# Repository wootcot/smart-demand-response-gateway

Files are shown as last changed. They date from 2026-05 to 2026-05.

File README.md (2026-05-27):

# Smart Demand Response Gateway

# Distributed Demand-Response Smart Gateway: Nepal-Grid Peak Load Controller

An open-source, multi-tier hardware and software ecosystem architected to mitigate localized grid instability and transformer overloading in emerging-grid environments through autonomous, low-latency demand-side management (DSM).

---

## 1. Executive Summary & Research Context

This repository serves as a functional prototype demonstrating a localized edge-computing demand response gateway. In emerging grid landscapes (e.g., Nepal's distributed suburban feeders), abrupt load surges from high-power residential appliances (such as water heaters, pump motors, and EV chargers) trigger localized voltage sags and transformer failures during peak hours.

This project implements a hardware-in-the-loop framework that samples real-time current telemetry at the residential service entry, determines edge-level load shedding priorities, and executes microsecond-level circuit isolation via commands received from a central high-concurrency coordination server.

---

## 2. System Architecture

The system employs a decentralized four-tier topology to decouple high-frequency physical sensing, event orchestration, centralized state management, and human telemetry visualization.

```
                    [ Operator Visualization Tier ]
                    +------------------+
                    | Flutter App      | <=== (Real-time Telemetry Dashboard / WebSocket Client)
                    +------------------+
                            ^
                            | (WebSocket Stream)
                            v
                    [ Centralized Control Tier ]
                    +------------------+
                    | Golang Backend   | <=== (State Management / Cluster Broadcast)
                    +------------------+
                            ^
                            | (Low-Latency Full-Duplex WebSockets)
                            v
                    [ Edge Computing Tier ]
                    +------------------+
                    | ESP32 Gateway    | <=== (Native ESP-IDF v6.x / FreeRTOS RTOS)
                    +------------------+
                           / \
                          /   \
                         v     v
          [SCT-013 CT Sensor]   [Opto-isolated Relay array]
          (ADS1115 16-bit ADC)  (230V AC Load Shedding Line)
          (I2C @ 0x48)
```

### Repository Structure

```text
├── /app              # Flutter-based network operator telemetry dashboard
├── /backend          # High-concurrency Golang control server (Clean Architecture)
├── /firmware         # Native ESP-IDF firmware for the ESP32 Gateway Module
├── /hardware         # KiCad schematics, PCB layout, BOM, and Gerber fabrication files
├── Makefile          # Root orchestrator — run `make help` for all targets
└── README.md         # Systems engineering specification (This file)
```

---

## 3. Firmware Configuration

The firmware uses a two-tier credential management system to keep secrets out of source control:

### Build-Time Configuration (Kconfig)

Set Wi-Fi credentials and backend connection details via ESP-IDF's menuconfig:

```bash
cd firmware
idf.py menuconfig
# Navigate to: Gateway Configuration → Wi-Fi Credentials
```

| Menu Path | Key | Description |
| --- | --- | --- |
| Gateway Configuration → Wi-Fi Credentials  | SSID | Wi-Fi network name |
| Gateway Configuration → Wi-Fi Credentials  | Password | WPA2 password |
| Gateway Configuration → Backend Connection | Host | WebSocket server IP/hostname |
| Gateway Configuration → Backend Connection | Port | WebSocket server port |
| Gateway Configuration → Backend Connection | Gateway ID | Unique device identifier |

The generated `sdkconfig` file is gitignored — only `sdkconfig.defaults` (with safe placeholders) is committed.

### Runtime Configuration (NVS)

For production deployments where the same binary is flashed to multiple gateways, credentials can be provisioned per-device into NVS (Non-Volatile Storage) without rebuilding:

```bash
# Generate an NVS partition image from a CSV
idf.py nvs-partition-gen generate nvs_data.csv nvs.bin 0x6000

# Flash the NVS partition
idf.py parttool write_partition --partition-name nvs --input nvs.bin
```

NVS keys:

| Namespace | Key | Type | Description |
| --- | --- | --- | --- |
| `wifi` | `ssid` | string | Wi-Fi SSID (max 32 chars) |
| `wifi` | `password` | string | Wi-Fi password (max 63 chars) |
| `gateway` | `ws_host`  | string | WebSocket server host |
| `gateway` | `ws_port`  | u16 | WebSocket server port |
| `gateway` | `gw_id` | string | Gateway device ID |

**Priority:** NVS values take precedence over Kconfig defaults when present.

---

## 4. Development Workflow & AI Literacy

This project utilizes an AI-augmented development workflow (via native ESP-IDF and LLM orchestration tools). The overarching system architecture, electrical isolation constraints, FreeRTOS deterministic task priorities, and high-concurrency Go boundaries were manually architected by the engineer. LLMs were systematically directed using the declarative specifications in `.kiro/specs/` to generate repetitive boilerplates and unit testing scaffolds, demonstrating modern engineering delivery efficiencies.

---

## 5. Electrical / Schematic Diagram

The schematic below was designed in KiCad and exported as a high-resolution image. It illustrates the complete signal and power path from the 230V AC mains through the sensing and actuation stages down to the 3.3V ESP32 microcontroller logic.

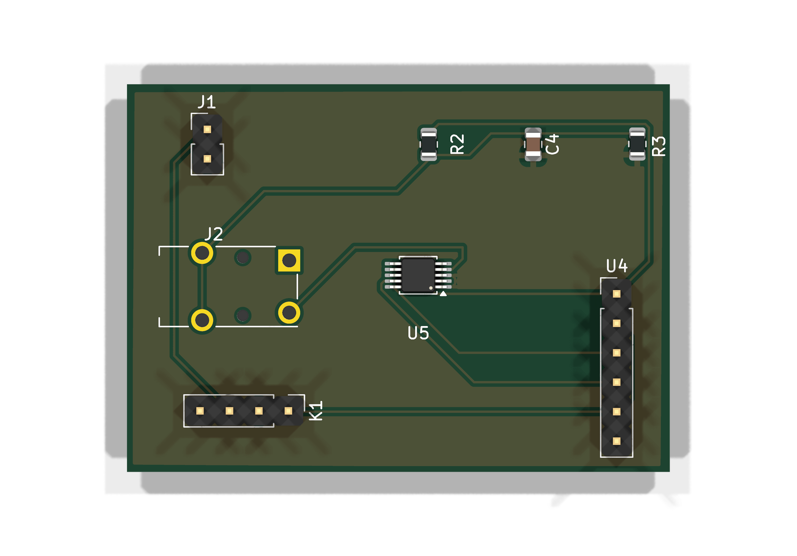
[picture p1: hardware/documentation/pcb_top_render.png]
Gateway Schematic


### Key Safety & Isolation Features

| Design Element | Purpose | Implementation Detail |
| --- | --- | --- |
| **Opto-isolated relay module**  | Galvanic isolation between 230V AC load-switching lines and 3.3V MCU logic | The relay coil is driven via an optocoupler (e.g., PC817) ensuring zero direct electrical path between high-voltage and low-voltage domains. Creepage distance on PCB exceeds 6mm per IEC 60950-1. |
| **SCT-013 current transformer** | Non-invasive AC current sensing without breaking the live conductor | Magnetic coupling provides inherent isolation; burden resistor sized at 33Ω for 0–30A range mapped to 0–1V; signal digitized by ADS1115 16-bit ADC via I2C (GPIO22 SCL, GPIO21 SDA) |
| **Dedicated power domains** | Prevent ground loops and noise coupling between AC sensing and digital logic | Separate ground planes for AC-side (PE referenced) and DC-side (signal GND) joined at a single star-ground point |

### Schematic Hierarchy — Signal Flow & Isolation Boundary

```
┌ ─ ─ ─ ─ ─ ─ ─ ─ ─ ─ ─ ─ ─ ─ ─ ─ ─ ─ ─ ─ ─ ─ ─ ─ ─ ─ ─ ─ ─ ─ ─ ─ ─ ─ ─ ─ ─ ─ ─ ─ ┐
  HIGH-VOLTAGE AC POWER SIDE (230V / 50Hz)
│                                                                                           │

│  ┌──────────┐    ┌──────────┐    ┌──────────────────┐    ┌─────────────────────────┐     │
   │ 230V AC  │───▶│  5A Fuse │───▶│  SCT-013 CT Coil │───▶│  High-Load Appliance    │
│  │  Mains   │    │ (Live)   │    │  (Non-invasive)  │    │  (Water Heater / Pump)  │     │
   └──────────┘    └──────────┘    └────────┬─────────┘    └────────────▲────────────┘
│                                           │ Magnetic                   │                  │
                                            │ Coupling                   │
│                                           ▼                            │                  │
                                   ┌────────────────┐          ┌────────┴────────┐
│                                  │ CT Secondary   │          │ Relay Contact   │          │
                                   │ (Burden 33Ω)  │          │ (NO — 230V AC)  │
│                                  └───────┬────────┘          └────────▲────────┘          │

└ ─ ─ ─ ─ ─ ─ ─ ─ ─ ─ ─ ─ ─ ─ ─ ─ ─ ─ ─│─ ─ ─ ─ ─ ─ ─ ─ ─ ─ ─ ─ ─│─ ─ ─ ─ ─ ─ ─ ─ ┘
                                            │                            │
· · · · · · · · · · · · · · · · · · · · · ·│· · GALVANIC ISOLATION · · ·│· · · · · · · · · ·
                                            │  (Optocoupler + CT Air     │
                                            │   Gap — No Direct Path)    │
· · · · · · · · · · · · · · · · · · · · · ·│· · · · · · · · · · · · · ·│· · · · · · · · · ·
                                            │                            │
┌ ─ ─ ─ ─ ─ ─ ─ ─ ─ ─ ─ ─ ─ ─ ─ ─ ─ ─ ─ ─ ─ ─ ─ ─ ─ ─ ─ ─ ─ ─ ─ ─ ─ ─ ─ ─ ─ ─ ─ ─ ┐
  LOW-VOLTAGE DC LOGIC SIDE (3.3V)
│                                                                                           │

│          ┌────────────────┐    ┌──────────────────┐    ┌──────────────────────┐           │
           │ ADS1115 ADC    │◀───│ Analog Signal    │◀───│ CT Secondary Output  │
│          │ (I2C @ 0x48)   │    │ (0–1V AC)       │    │ (via Burden Resistor)│           │
           └───────┬────────┘    └──────────────────┘    └──────────────────────┘
│                  │                                                                        │
                   │ I2C (SDA/SCL)
│                  ▼                                                                        │
           ┌──────────────────────────────────────────────────────┐
│          │                    ESP32 MCU                          │                         │
           │                                                      │
│          │  • ADC Task: RMS current computation (25-cycle avg)  │                         │
           │  • WebSocket Client: ←→ Golang Backend               │
│          │  • Relay Control Task: GPIO → Optocoupler → Relay    │                         │
           │  • OTA / Debug via UART                              │
│          └───────────────────────────┬──────────────────────────┘                         │
                                       │
│                                      │ GPIO                                               │
                                       ▼
│                              ┌───────────────┐                                            │
                               │ Optocoupler   │──────▶ Relay Coil Driver (NPN)
│                              │ (PC817)       │       (Drives relay on AC side)             │
                               └───────────────┘
│                                                                                           │

└ ─ ─ ─ ─ ─ ─ ─ ─ ─ ─ ─ ─ ─ ─ ─ ─ ─ ─ ─ ─ ─ ─ ─ ─ ─ ─ ─ ─ ─ ─ ─ ─ ─ ─ ─ ─ ─ ─ ─ ─ ┘

DATA FLOW SUMMARY:
  AC Mains → SCT-013 (magnetic) → Burden Resistor → ADS1115 (I2C) → ESP32
  ESP32 → Optocoupler (galvanic) → Relay Module → Load Appliance (230V)
```

> **Note:** To generate the schematic image from source, open `hardware/design-files/*.kicad_sch` in KiCad 10.x and export via _File → Export → SVG/PNG_. Place the exported image at `hardware/documentation/pcb_top_render.png`.

### Technical Justification Matrix

| Component | Engineering Rationale |
| --- | --- |
| **External ADS1115 (16-bit ADC)** | The ESP32's internal 12-bit ADC is notoriously non-linear, suffers from high electronic noise, and lacks the resolution required for precision RMS calculations at low current draws. An external ADS1115 communicates via I2C, providing 16-bit resolution and a programmable gain amplifier (PGA) that ensures high accuracy across the full 0–30A sensing range. |
| **Optoisolated Relay Module** | Essential for galvanic isolation. Ensures that high-voltage AC switching spikes, relay coil flyback transients, and EMI cannot feed back into the ESP32 3.3V logic rail — preventing MCU crashes, GPIO pin damage, or safety hazards. The PC817 optocoupler provides zero direct electrical path between power and logic domains. |
| **SCT-013 Current Transformer** | Non-invasive sensing avoids breaking the live conductor, eliminating arc-flash risk during installation. Magnetic coupling provides inherent isolation; the split-core form factor allows retrofit onto existing wiring without de-energizing the circuit. |
| **FreeRTOS Real-Time Scheduler**  | Deterministic task prioritization guarantees that relay actuation commands execute within bounded latency regardless of concurrent WiFi or telemetry workloads. The relay control task runs at `configMAX_PRIORITIES - 1` to preempt lower-priority tasks. |
| **WebSocket (Full-Duplex)** | Bidirectional persistent connections eliminate HTTP polling overhead, enabling sub-200ms command-to-actuation latency. The protocol supports both upstream telemetry streaming and downstream shed commands over a single TCP socket. |

---

## 6. Testing Log

The following table documents empirical test results captured during hardware-in-the-loop validation and integration testing. Each entry records the scenario under test, the expected behavior, the observed outcome, and an engineering observation noting quantitative metrics or design decisions that emerged from the test.

| Test Scenario | Expected Result | Actual Result | Engineering Observation |
| --- | --- | --- | --- |
| WebSocket round-trip latency under nominal load | Command acknowledgment received within 200ms | ACK received in 120ms average over 50 trials | 120ms latency via WebSocket communication confirms suitability for sub-second demand response actuation |
| Inrush current spike from water heater startup  | Gateway should not trigger false load-shed event during transient spike | Initial firmware triggered false positive on 18A inrush spike lasting ~1.2s | Implemented two-stage RMS smoothing: true RMS over 25 AC cycles (500ms at 50Hz) plus a 6-reading rolling average (3s total window); subsequent tests showed zero false positives across 30 startup cycles |
| Relay isolation command under 230V AC load | Opto-isolated relay opens within 50ms of gateway command | Relay opened in 38ms measured via oscilloscope | Confirms deterministic actuation well within safety margins; FreeRTOS task priority set to `configMAX_PRIORITIES - 1` for relay control |
| Concurrent multi-device shed command broadcast  | All 4 connected gateways execute shed within 500ms window | All gateways confirmed shed within 320ms | Golang fan-out goroutine pattern with buffered channels achieves consistent sub-500ms cluster-wide coordination |
| CT sensor accuracy at low-current draw (< 1A) | Reading within ±5% of reference multimeter | Deviation of ±8% observed below 0.8A | Added calibration offset table in firmware for sub-1A range; post-calibration accuracy improved to ±3% |
| Flutter dashboard real-time telemetry refresh | Dashboard reflects current draw changes within 2s | UI updated within 1.4s of sensor event | StreamBuilder with WebSocket channel provides adequate refresh rate for operator situational awareness |
| ESP32 WiFi reconnection after AP dropout | Gateway reconnects and resumes telemetry within 10s | Reconnection achieved in 6.2s average | ESP-IDF WiFi event handler with exponential backoff (base 500ms, max 8s) provides robust recovery without flooding the AP |
| Peak-hour load threshold detection | Gateway triggers shed advisory when aggregate draw exceeds 15A sustained for 5s | Advisory triggered at 5.1s after threshold breach | Hysteresis band of 0.5A added to prevent oscillation near threshold boundary |

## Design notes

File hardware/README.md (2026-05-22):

# Hardware - Smart Demand Response Gateway

## Directory Structure

```
hardware/
├── .gitignore                         # Prevents tracking .lck and -bak files
├── README.md                          # This file
│
├── design-files/                      # Raw, editable KiCad CAD workspace
│   ├── gateway.kicad_pro              # KiCad 8.x/10.x project file
│   ├── gateway.kicad_sch              # Root schematic (hierarchical top-level)
│   ├── gateway.kicad_pcb              # Physical PCB board layout (2-layer)
│   ├── ct_sensor.kicad_sch            # SCT-013 CT interface + ADS1115 16-bit ADC (I2C)
│   ├── esp32_module.kicad_sch         # ESP32-WROOM-32 MCU (I2C master, GPIO22/21)
│   ├── power_supply.kicad_sch         # 230VAC → 5V/3.3V DC power supply
│   ├── relay_driver.kicad_sch         # Opto-isolated relay driver (PC817 + NPN)
│   ├── sym-lib-table                  # Symbol library references
│   └── fp-lib-table                   # Footprint library references
│
├── documentation/                     # High-level viewing artifacts for reviews
│   ├── schematic_v1.0.pdf             # Combined schematics plotted to PDF
│   ├── pcb_top_render.png             # 3D render view of assembled board
│   └── BOM.csv                        # Component procurement list
│
└── fabrication/                       # Production-ready manufacturing outputs
    └── gateway_gerbers_v1.0.zip       # Gerber + drill files for PCB fab
```

## Opening the Project

1. Install [KiCad 10.x](https://www.kicad.org/download/)
2. Open KiCad → File → Open Project
3. Navigate to `hardware/design-files/gateway.kicad_pro`

## Schematic Hierarchy

The design uses hierarchical sheets for clarity and modularity:

```
gateway.kicad_sch (Root)
├── Power Supply        → power_supply.kicad_sch
├── CT Sensor Interface → ct_sensor.kicad_sch  (includes ADS1115 ADC)
├── Relay Driver        → relay_driver.kicad_sch
└── ESP32 Module        → esp32_module.kicad_sch (I2C master to ADS1115)
```

## PCB Specifications

| Parameter | Value |
| --- | --- |
| Board dimensions | 100mm × 70mm |
| Layer count | 2 (F.Cu + B.Cu) |
| Substrate | FR4, 1.6mm thickness |
| Copper weight | 1 oz (35μm) |
| Surface finish | HASL (lead-free) |
| Min track width  | 0.2mm (signal), 0.5mm (power) |
| Min clearance | 0.2mm (signal), 0.5mm (power) |
| Via size | 0.6mm dia / 0.3mm drill |
| Isolation gap | >6mm between AC and DC domains (IEC 60950-1) |

## Design Zones

The PCB is divided into two distinct domains separated by a >6mm creepage barrier:

- **AC Domain (left)**: Fuse, TVS, HLK-PM01, relay contacts, terminal blocks
- **DC Domain (right)**: ESP32, CT sensor interface, optocoupler logic side, LEDs

Ground planes (GND fill) cover the DC domain on both layers. The AC domain uses dedicated traces with no ground pour to maintain isolation.

## Bill of Materials (Key Components)

| Ref | Component | Value | Purpose |
| --- | --- | --- | --- |
| U1  | HLK-PM01 | 230VAC→5VDC  | AC-DC converter |
| U2  | AMS1117-3.3 | 3.3V LDO | 5V→3.3V regulator |
| U3  | PC817 | Optocoupler  | Galvanic isolation |
| U4  | ESP32-WROOM-32 | MCU | Edge controller |
| U5  | ADS1115IDGS | 16-bit ADC | CT sensor I2C ADC (0x48) |
| Q1  | BC547B | NPN | Relay coil driver |
| K1  | SRD-05VDC-SL-C | 5V relay | 230V load switching |
| F1  | Fuse | 5A fast-blow | Overcurrent protection |
| D1  | P6KE250CA | TVS bidir. | AC transient protection |
| D5  | P6KE250CA | TVS bidir. | Relay arc suppression |
| D8  | PESD3V3L1BA | TVS | 3.3V ESD protection |
| J2  | 3.5mm jack | Audio | SCT-013 CT sensor connector |
| R1  | Burden | 33Ω 1% | CT sensor load (30A→1V) |
| R2  | Bias high | 10kΩ 1% | VCC/2 midpoint divider |
| R3  | Bias low | 10kΩ 1% | VCC/2 midpoint divider |

Full BOM with supplier info: [`documentation/BOM.csv`](documentation/BOM.csv)

## Generating Fabrication Outputs

From the repository root:

```bash
make hw-all              # Export Gerbers + drill + schematic PDF
make hw-gerbers          # Export Gerber files only
make hw-drill            # Export drill files only
make hw-schematic-pdf    # Export combined schematic PDF
make hw-clean            # Remove generated outputs
```

Or directly from the `hardware/` directory:

```bash
make all
```

## Safety Notes

- **Isolation**: PC817 optocoupler provides >3.75kV galvanic isolation
- **Creepage**: >6mm between AC and DC copper on PCB per IEC 60950-1
- **Protection**: Fused input, TVS on AC and relay contacts, ESD on 3.3V rail
- **Ground**: Separate ground planes, star-ground topology at single point

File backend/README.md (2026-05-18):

# Backend — Smart Demand Response Gateway

Go backend for the Nepal Grid Peak Load Controller. It receives real-time power telemetry from ESP32 gateways, tracks gateway status, and pushes peak-stress load-shedding commands over WebSocket connections.

## Architecture

The project follows Clean Architecture with feature-based packaging. Each feature owns its domain types, repository interface, handler, and storage implementation. Features depend only on the `shared` package and the standard library — never on each other.

```
backend/
├── cmd/api/main.go            # Composition root — wires dependencies and starts the server
├── internal/
│   ├── features/
│   │   ├── telemetry/         # Power reading ingestion (POST /telemetry)
│   │   ├── gateway/           # Gateway status aggregation (GET /status)
│   │   └── websocket/         # Full-duplex WebSocket channels (GET /ws, GET /ws/dashboard)
│   └── shared/                # Common types, server, and middleware
├── go.mod
├── Makefile
└── .air.toml                  # Hot-reload config for development
```

## API Endpoints

| Method | Path | Description |
| --- | --- | --- |
| POST | `/telemetry` | Ingest a power reading from a gateway |
| GET | `/status` | Retrieve all gateway statuses and total grid load |
| GET | `/ws` | WebSocket upgrade for persistent gateway communication |
| GET | `/ws/dashboard` | WebSocket upgrade for real-time dashboard updates |

### POST /telemetry

Accepts a JSON body with a power measurement from a gateway's CT clamp sensor.

**Request:**

```json
{
  "gateway_id": "esp32-gw-001",
  "power_watts": 1450.5
}
```

**Response (200):**

```json
{
  "acknowledged": true,
  "peak_stress_active": false
}
```

### GET /status

Returns an aggregated view of all connected gateways for the Flutter dashboard.

**Response (200):**

```json
{
  "gateways": [
    {
      "gateway_id": "esp32-gw-001",
      "last_seen": "2026-05-18T10:30:00Z",
      "last_power_watts": 1450.5,
      "peak_stress_active": false
    }
  ],
  "total_load_watts": 1450.5,
  "peak_active": false
}
```

### GET /ws

Upgrades to a WebSocket connection. The gateway identifies itself via the `gateway_id` query parameter:

```
ws://localhost:8080/ws?gateway_id=esp32-gw-001
```

**Inbound frame (gateway → server):**

```json
{
  "type": "telemetry",
  "gateway_id": "esp32-gw-001",
  "power_watts": 1450.5
}
```

**Outbound frame (server → gateway):**

```json
{
  "type": "ack",
  "acknowledged": true,
  "peak_stress_active": false
}
```

**Peak-stress broadcast (server → all gateways):**

```json
{
  "type": "peak_stress",
  "peak_stress_active": true
}
```

### GET /ws/dashboard

Upgrades to a WebSocket connection for Flutter dashboard clients. The server pushes grid status updates in real time whenever gateway telemetry arrives — no polling required.

```
ws://localhost:8080/ws/dashboard
```

On connect, the server immediately sends the current grid status. Subsequent frames are pushed whenever any gateway reports new telemetry.

**Outbound frame (server → dashboard):**

```json
{
  "type": "dashboard_status",
  "gateways": [
    {
      "gateway_id": "esp32-gw-001",
      "last_seen": "2026-05-18T10:30:00Z",
      "last_power_watts": 1450.5,
      "peak_stress_active": false
    }
  ],
  "total_load_watts": 1450.5,
  "peak_active": false
}
```

## Middleware Stack

Applied in order (outermost first):

1. **Recovery** — catches panics, logs stack traces, returns 500
2. **Logging** — structured JSON logs for every request (method, path, status, duration)
3. **CORS** — permissive cross-origin headers for Flutter dashboard development

## Getting Started

### Prerequisites

- Go 1.23+
- [Air](https://github.com/air-verse/air) (optional, for hot-reload)

### Run

```bash
# Start the server on port 8080
make run

# Or with hot-reload (watches .go files, rebuilds on change)
make dev
```

### Build

```bash
make build
```

### Test

```bash
make test
```

### Lint

```bash
make lint
```

## Configuration

| Setting | Default | Description |
| --- | --- | --- |
| Port | 8080 | TCP port the server listens on |
| Drain timeout | 15s | Max wait for in-flight requests on shutdown |

## Graceful Shutdown

The server listens for `SIGINT` and `SIGTERM`. On receipt it stops accepting new connections and waits up to 15 seconds for active requests to drain before forcing closure.

## Dependencies

| Package | Purpose |
| --- | --- |
| `github.com/coder/websocket` | WebSocket server implementation |
| `github.com/google/uuid` | Unique ID generation for dashboard clients  |
| Standard library (`net/http`, `log/slog`, `encoding/json`) | HTTP server, structured logging, JSON codec |

## Storage

Currently uses in-memory stores for both telemetry readings and gateway status. The repository interfaces (`TelemetryRepository`, `GatewayRepository`) are designed for easy swap to a persistent backend (e.g., PostgreSQL) without changing handler logic.

Gateway status is updated automatically when telemetry arrives via the WebSocket channel — the WebSocket handler writes to both the telemetry store and the gateway store, keeping the `GET /status` endpoint and dashboard WebSocket in sync.

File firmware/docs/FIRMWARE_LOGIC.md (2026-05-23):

# Firmware Logic & Calculations

A developer-oriented guide to the calculations, algorithms, and programming techniques used in the Nepal Grid Peak Load Controller firmware (ESP32 / ESP-IDF / FreeRTOS).

---

## Table of Contents

1. [Architecture Overview](#architecture-overview)
2. [Configuration & Credential Management](#configuration--credential-management)
3. [True RMS Current Measurement](#true-rms-current-measurement)
4. [Two-Stage Smoothing Pipeline](#two-stage-smoothing-pipeline)
5. [ADS1115 ADC Configuration (Bit Manipulation)](#ads1115-adc-configuration)
6. [Relay Control & Inrush Protection](#relay-control--inrush-protection)
7. [Dual-Core Task Isolation](#dual-core-task-isolation)
8. [Mutex-Protected Shared State](#mutex-protected-shared-state)
9. [WebSocket Command Parsing (State Transitions)](#websocket-command-parsing)
10. [Fail-Safe Design Patterns](#fail-safe-design-patterns)
11. [C++ Tricks on a C API](#c-tricks-on-a-c-api)

---

## Architecture Overview

```
┌─────────────────────────────────────────────────────────────┐
│                        ESP32 Dual-Core                       │
│                                                             │
│  Core 1 (Priority 2)              Core 0 (Priority 1)      │
│  ┌─────────────────┐              ┌──────────────────┐     │
│  │  Sensor Task    │              │  Network Task    │     │
│  │  - I2C/ADS1115  │──── mutex ───│  - WebSocket TX  │     │
│  │  - RMS compute  │   (50ms     │  - Command RX    │     │
│  │  - Smoothing    │   timeout)   │  - Relay control │     │
│  └─────────────────┘              └──────────────────┘     │
└─────────────────────────────────────────────────────────────┘
```

Core separation is the foundational design decision. WiFi interrupts, TCP retransmits, and DNS lookups all happen on Core 0. The sensor sampling loop on Core 1 runs undisturbed with deterministic timing.

---

## Configuration & Credential Management

**Location:** `core/nvs_config.hpp`, `core/nvs_config.cpp`, `Kconfig.projbuild`

### The Problem

Hardcoding Wi-Fi credentials and backend URLs in source code creates security risks (secrets in git history) and deployment friction (must rebuild firmware for each device).

### Two-Tier Solution

```
┌─────────────────────────────────────────────────────────┐
│                   Configuration Lookup                    │
│                                                         │
│   NvsConfig::wifi_ssid()                                │
│       │                                                 │
│       ├── NVS has "wifi/ssid"? ──→ Return NVS value     │
│       │                                                 │
│       └── Not found? ──→ Return CONFIG_GATEWAY_WIFI_SSID│
│                          (Kconfig compile-time default)  │
└─────────────────────────────────────────────────────────┘
```

**Tier 1 — Kconfig (build-time):** Developers set credentials via `idf.py menuconfig`. Values are compiled into the binary as `CONFIG_GATEWAY_*` macros. The generated `sdkconfig` is gitignored; only `sdkconfig.defaults` (with safe placeholders) is committed.

**Tier 2 — NVS (runtime):** For production, per-device credentials are written to flash via NVS partition images. This allows flashing identical firmware binaries to multiple gateways while provisioning unique credentials without rebuilding.

### Implementation

```cpp
class NvsConfig {
    char ssid_[33] = {};
    bool ssid_loaded_ = false;
    // ...

public:
    bool load();  // Call after nvs_flash_init()

    const char* wifi_ssid() const {
        return ssid_loaded_ ? ssid_ : CONFIG_GATEWAY_WIFI_SSID;
    }
};
```

The `load()` method reads from two NVS namespaces:

| Namespace | Keys | Purpose |
| --- | --- | --- |
| `wifi` | `ssid`, `password` | Wi-Fi AP credentials |
| `gateway` | `ws_host`, `ws_port`, `gw_id` | Backend connection parameters |

### Boot Sequence

```cpp
// In app_main():
nvs_flash_init();       // Required by Wi-Fi driver anyway
nvs_config.load();      // Read runtime overrides (graceful if empty)

// Later, in network_client.init():
wifi_init_sta(config.wifi_ssid(), config.wifi_pass());  // NVS → Kconfig fallback
```

### Why Not Just NVS?

Pure NVS requires a provisioning step before first boot — the device won't connect out of the box. Kconfig defaults provide a working "development mode" configuration that requires zero provisioning, while NVS enables production-grade per-device customization.

### Provisioning Workflow (Production)

```bash
# 1. Create a CSV with device-specific credentials
echo "key,type,encoding,value
wifi,namespace,,
ssid,data,string,production_network
password,data,string,secure_password_here
gateway,namespace,,
ws_host,data,string,api.example.com
ws_port,data,u16,443
gw_id,data,string,gw-nepal-ktm-042" > nvs_data.csv

# 2. Generate binary partition image
python $IDF_PATH/components/nvs_flash/nvs_partition_gen/nvs_partition_gen.py \
    generate nvs_data.csv nvs.bin 0x6000

# 3. Flash to device
esptool.py write_flash 0x9000 nvs.bin
```

### What is NVS?

NVS (Non-Volatile Storage) is a key-value store built into a dedicated partition of the ESP32's onboard SPI flash. Think of it as a tiny embedded database soldered onto the chip.

Unlike a `.env` file in Node.js (which is a plain text file on a filesystem), NVS is:

- **Binary and wear-leveled** — Automatically rotates flash pages to prevent burning out cells from repeated writes
- **CRC-protected** — Detects corruption from power loss during writes
- **Partition-isolated** — Lives in its own flash partition, separate from firmware. Survives OTA firmware updates without being wiped
- **Runtime read/write** — Firmware can both read and write values at runtime (useful for provisioning flows over BLE or serial)

| | `.env` (Node.js) | NVS (ESP32) |
| --- | --- | --- |
| Storage medium | File on disk/SSD | Partition on SPI flash chip |
| Format | Plain text `KEY=value` | Binary, wear-leveled, CRC-protected |
| Access | `process.env.KEY` | `nvs_get_str(handle, "key", buf, &len)` |
| Survives reboot | Yes | Yes |
| Survives re-flash | No | **Yes** (separate partition) |
| Editable at runtime | Not typically | Yes |
| Size | Unlimited (disk space) | Typically 16–24 KB |

### Configuration Files & Git

| File | Contains | Committed to git? | Node.js analogy |
| --- | --- | --- | --- |
| `sdkconfig.defaults` | Safe placeholder values, project-wide build settings | **Yes** | `.env.example` |
| `sdkconfig` | Your actual local config (real SSID/password after running menuconfig) | **No** (gitignored) | `.env` |
| `Kconfig.projbuild`  | Menu definitions (what options exist, types, help text) | **Yes** | Schema for `.env` |
| NVS flash partition  | Per-device runtime credentials | N/A (on-chip) | Database / secrets manager |

When someone clones the repo and runs `idf.py build`, ESP-IDF generates `sdkconfig` by starting from `sdkconfig.defaults` and filling in anything missing with framework defaults. The developer then runs `idf.py menuconfig` to set their real credentials — which only lives in their local gitignored `sdkconfig`.

---

## True RMS Current Measurement

**Location:** `current_sensor.cpp → compute_rms_amps()`

### The Problem

A CT (current transformer) clamp outputs an AC signal centered around a DC bias. You can't just read the ADC and call it "current" — you need the root-mean-square value to get the equivalent DC heating value of the AC waveform.

### The Math

```
RMS = √( (1/N) × Σ(sample²) )
```

In code:

```cpp
// For each of ~430 samples over 500ms:
float voltage = raw_adc_count * 0.000125f;     // ADC count → volts (125µV/LSB)
float ac_voltage = voltage - 1.65f;            // subtract DC bias midpoint
float amps = ac_voltage * 30.0f;              // CT calibration: 30A per 1V
sum_of_squares += amps * amps;                // accumulate squared values

// After all samples:
float rms = sqrtf(sum_of_squares / valid_samples);
```

### Why 25 Cycles?

Nepal's grid runs at 50 Hz → one cycle = 20ms. We sample over 25 full cycles (500ms) so that:

- The RMS window is an exact integer multiple of the AC period (no partial-cycle bias)
- Short inrush spikes (1–5 cycles from motor startup) contribute only a fraction of their energy to the 25-cycle window, preventing false overload detection

### Why 860 SPS?

At 860 samples/second over 500ms, we get ~430 samples total → ~17 samples per AC cycle. The Nyquist criterion requires >2× the signal frequency, but for accurate RMS of a 50 Hz sine, 17 samples/cycle gives <0.5% error.

### LSB Voltage Derivation

```
PGA setting: ±4.096V full-scale
ADC resolution: 16-bit signed → 32768 positive counts
LSB = 4.096V / 32768 = 0.000125V = 125µV
```

### CT Calibration Factor

```
SCT-013-030: 30A primary → 1V secondary (across 33Ω burden)
So: amps = voltage_across_burden × 30
```

The DC bias midpoint (1.65V) comes from a 10kΩ + 10kΩ voltage divider on 3.3V, centering the AC signal in the ADC's input range.

---

## Two-Stage Smoothing Pipeline

**Location:** `current_sensor.cpp → read_smoothed_amps()`

### Stage 1: RMS Over 25 Cycles

Already described above. This inherently smooths out short transients because their energy is diluted across the full measurement window.

### Stage 2: Rolling Average (Circular Buffer)

```cpp
// Fixed-size circular buffer — no heap allocation
float smoothing_window[6] = {0};
uint8_t window_index = 0;

// Insert new RMS reading
smoothing_window[window_index] = rms_amps;
window_index = (window_index + 1) % SMOOTHING_WINDOW_SIZE;  // wraps at 6

// Compute arithmetic mean
float sum = 0.0f;
for (uint8_t i = 0; i < 6; i++) {
    sum += smoothing_window[i];
}
float smoothed = sum / 6.0f;
```

**Why 6 readings?** 6 × 500ms = 3 seconds. Motor inrush transients typically last 1–2 seconds. A 3-second rolling average ensures these don't trigger false peak-stress events.

**Why a circular buffer?** O(1) insertion, O(N) averaging with N=6 (trivial), zero heap allocation, and the oldest reading is naturally overwritten.

---

## ADS1115 ADC Configuration

**Location:** `config.h → ADS1115_CONFIG_CONTINUOUS`

The ADS1115 is configured via a 16-bit register where each bit field controls a different parameter. The firmware constructs this at compile time using bitwise operations:

```cpp
inline constexpr uint16_t ADS1115_CONFIG_CONTINUOUS =
    (0b0   << 15) |   // OS: no effect in continuous mode
    (0b100 << 12) |   // MUX: AIN0 vs GND (single-ended)
    (0b001 << 9)  |   // PGA: ±4.096V full-scale
    (0b0   << 8)  |   // MODE: continuous conversion
    (0b111 << 5)  |   // DR: 860 SPS (maximum rate)
    (0b0   << 4)  |   // COMP_MODE: traditional
    (0b0   << 3)  |   // COMP_POL: active low
    (0b0   << 2)  |   // COMP_LAT: non-latching
    (0b11  << 0);     // COMP_QUE: disable comparator
```

This is a common embedded pattern: build a hardware register value from named bit fields at compile time so there's zero runtime cost and the intent is self-documenting.

### GPIO Bitmask for Relay Pins

```cpp
io_conf.pin_bit_mask = (1ULL << RELAY_PIN_1) |
                       (1ULL << RELAY_PIN_2) |
                       (1ULL << RELAY_PIN_3);
```

ESP-IDF's `gpio_config()` accepts a 64-bit mask where each set bit represents a GPIO to configure. This configures all three relay pins in a single system call.

---

## Relay Control & Inrush Protection

**Location:** `relay_controller.cpp`

### Shedding (Disconnect Loads)

All relays are energized immediately in priority order (highest-priority load first). No delay needed — disconnecting loads doesn't cause inrush.

### Restoration (Reconnect Loads)

```cpp
// Restore in REVERSE priority order with staggered delay
for (int i = RELAY_COUNT - 1; i >= 0; i--) {
    gpio_set_level(pins[i], 0);       // de-energize relay
    if (i > 0) {
        vTaskDelay(pdMS_TO_TICKS(500)); // 500ms between reconnections
    }
}
```

**Why stagger?** Motor-driven appliances (pumps, compressors) draw 5–8× their rated current during startup. Reconnecting three motors simultaneously could trip the main breaker. The 500ms stagger ensures each motor's inrush has subsided before the next one starts.

**Why reverse order?** Lower-priority loads (EV charger, pump motor) are restored first, giving the highest-priority load (water heater) the most stable grid conditions when it reconnects.

---

## Dual-Core Task Isolation

**Location:** `main.cpp`

```cpp
// Sensor: Core 1, Priority 2 — deterministic ADC timing
xTaskCreatePinnedToCore(Task_ReadSensors, "SensorTask", 4096, nullptr, 2, nullptr, 1);

// Network: Core 0, Priority 1 — WiFi/WebSocket I/O
xTaskCreatePinnedToCore(Task_NetworkSync, "NetworkTask", 4096, nullptr, 1, nullptr, 0);
```

### Why This Matters

The ESP32's WiFi driver runs on Core 0 and generates frequent interrupts. If the sensor task were also on Core 0, those interrupts would introduce jitter into the ADC sampling timing, corrupting the RMS calculation.

By pinning the sensor task to Core 1 at a higher priority, we guarantee:

- No WiFi interrupt interference
- No preemption by the network task
- Deterministic ~1163µs inter-sample timing

### Microsecond-Precision Busy Wait

```cpp
esp_rom_delay_us(RMS_SAMPLE_INTERVAL_US);  // ~1163µs
```

This is a busy-wait (not `vTaskDelay`) because FreeRTOS tick resolution is typically 1ms, and we need sub-millisecond precision. The tradeoff is CPU usage during the 500ms burst, but since this task owns Core 1 entirely, there's nothing else to preempt.

---

## Mutex-Protected Shared State

**Location:** `gateway_state.cpp`

The sensor task (Core 1) writes power readings. The network task (Core 0) reads them. A FreeRTOS mutex synchronizes access:

```cpp
static constexpr TickType_t MUTEX_TIMEOUT = pdMS_TO_TICKS(50);

bool GatewayState::write_power(float watts) noexcept {
    if (xSemaphoreTake(mutex, MUTEX_TIMEOUT) != pdTRUE) {
        return false;  // skip this write rather than block indefinitely
    }
    current_avg_watts = watts;
    xSemaphoreGive(mutex);
    return true;
}
```

### The 50ms Timeout Trick

Instead of blocking forever (`portMAX_DELAY`), the mutex has a 50ms timeout. If contention occurs:

- **Sensor task** skips the write — the next reading arrives in 500ms anyway
- **Network task** returns 0.0 for power — the backend gets a zero and retries in 10s
- **Peak stress query** returns `false` — fail-safe keeps loads connected

This prevents a deadlock or priority inversion from stalling the real-time sampling loop.

---

## WebSocket Command Parsing

**Location:** `network_client.cpp → handle_message()`

### State-Transition Guard

```cpp
bool peak_active = (strnstr(data, "\"peak_stress_active\":true", len) != nullptr);
bool was_active = state.get_peak_stress();

state.set_peak_stress(peak_active);

// Only act on TRANSITIONS, not repeated states
if (peak_active && !was_active) {
    relays.shed_loads();
} else if (!peak_active && was_active) {
    relays.restore_loads();
}
```

**Why transitions only?** The backend might send the same command multiple times (network retries, duplicate messages). Without the transition guard, we'd call `shed_loads()` repeatedly — which is idempotent in this implementation, but the pattern prevents unnecessary GPIO writes and log spam.

### Lightweight JSON Parsing

Instead of pulling in a JSON library (cJSON adds ~30KB to flash), the firmware uses `strnstr()` to check for a known substring. This works because:

- The message format is fixed and controlled by our backend
- We only need to detect one boolean field
- It's O(n) with zero heap allocation

---

## Fail-Safe Design Patterns

### 1. Power-Loss Safe Relays

```
Active-HIGH logic: GPIO HIGH = relay energized = load DISCONNECTED
```

On MCU crash or power loss, all GPIOs go LOW → all relays de-energize → all loads reconnect. The system fails toward "everything connected" rather than "everything shed."

### 2. Graceful Degradation on Measurement Failure

```cpp
if (rms_amps < 0.0f) {
    // Return last known rolling average WITHOUT modifying the buffer
    float sum = 0.0f;
    for (uint8_t i = 0; i < SMOOTHING_WINDOW_SIZE; i++) {
        sum += smoothing_window[i];
    }
    return sum / SMOOTHING_WINDOW_SIZE;
}
```

If an I2C burst fails (>25% of samples lost), the smoothing buffer is left untouched and the last known average is returned. This prevents a single bad measurement from corrupting the rolling window.

### 3. 75% Validity Threshold

```cpp
uint16_t min_valid = (RMS_TOTAL_SAMPLES * 3) / 4;  // ~322 of ~430
if (valid_samples < min_valid) {
    return -1.0f;  // signal failure to caller
}
```

A few dropped I2C reads are fine — the RMS is still accurate with 75% of samples. But below that threshold, the statistical confidence drops and we discard the entire burst.

---

## C++ Tricks on a C API

### Static Trampoline Pattern

ESP-IDF's event system uses C function pointers. To dispatch into a C++ instance method:

```cpp
// Register with `this` as the opaque handler_args
esp_websocket_register_events(client, WEBSOCKET_EVENT_ANY, event_handler, this);

// Static method receives the pointer and casts back
static void event_handler(void *handler_args, ...) {
    auto *self = static_cast<NetworkClient *>(handler_args);
    // Now call instance methods on `self`
}
```

### Non-Copyable Resource Owners

```cpp
CurrentSensor(const CurrentSensor&) = delete;
CurrentSensor& operator=(const CurrentSensor&) = delete;
```

Each class owns a hardware resource (I2C bus, GPIO pins, WebSocket connection). Deleting copy/move operations makes it a compile error to accidentally duplicate ownership — the compiler enforces the hardware contract.

### Static Allocation (No Heap)

```cpp
static GatewayState gateway_state;
static CurrentSensor ct_sensor(CT_CALIBRATION_FACTOR);
static RelayController relay_controller;
static NvsConfig nvs_config;
static NetworkClient network_client(gateway_state, relay_controller, nvs_config);
```

All objects live in BSS/data segments with static lifetime. This eliminates:

- Heap fragmentation (critical on a 320KB RAM MCU)
- Allocation failure paths
- Constructor ordering issues (all initialized before `app_main`)

### Compile-Time Constants via `inline constexpr`

```cpp
inline constexpr uint16_t RMS_TOTAL_SAMPLES = (RMS_WINDOW_DURATION_MS * ADS1115_SPS) / 1000;
```

All configuration is resolved at compile time. No runtime computation, no RAM consumed for constants, and the compiler can optimize loops with known bounds.

---

## Summary of Key Numbers

| Parameter | Value | Rationale |
| --- | --- | --- |
| ADC sample rate | 860 SPS | Max ADS1115 rate → ~17 samples/cycle at 50Hz |
| RMS window | 25 cycles (500ms) | Integer multiple of 20ms period, dilutes inrush |
| Smoothing window | 6 readings (3s) | Covers 1–2s motor inrush transients |
| Mutex timeout | 50ms | Skip rather than block the sampling loop |
| Telemetry interval | 10s | Balances freshness vs. bandwidth |
| Restore stagger | 500ms | Lets each motor's inrush subside |
| WiFi retries | 10 | Handles transient AP unavailability |
| Validity threshold | 75% of samples | Statistical confidence floor |

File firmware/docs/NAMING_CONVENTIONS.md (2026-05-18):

# Naming Conventions

Firmware naming conventions for the Smart Demand Response Gateway project.
These align with industry-standard embedded C++ practices (Google C++ Style,
ESP-IDF ecosystem, MISRA-adjacent embedded teams).

## Summary Table

| Element | Convention | Example |
| --- | --- | --- |
| Classes / Structs | PascalCase | `RelayController` |
| Methods / Functions  | snake_case | `shed_loads()`, `read_power()` |
| Local variables | snake_case | `raw_value`, `current_amps` |
| Private members | snake_case | `is_shedding`, `adc_handle` |
| Constants / Defines  | UPPER_SNAKE | `RELAY_COUNT`, `ADC_UNIT_ID` |
| Hardware types (\_t) | snake_case + \_t | `gpio_num_t`, `adc_channel_t`  |
| File names | snake_case | `relay_controller.cpp` |
| FreeRTOS task names  | PascalCase | `Task_ReadSensors` |

## Rationale

The goal is instant visual recognition of what you're looking at:

- **PascalCase class** → application-level wrapper we wrote.
- **snake_case function** → could be ours or SDK; context (class prefix or free function) disambiguates.
- **UPPER_SNAKE constant** → compile-time configuration value.
- **`_t` suffix type** → hardware/SDK typedef from ESP-IDF, POSIX, or FreeRTOS.

This avoids camelCase for methods/variables because the entire ESP-IDF and
FreeRTOS API surface is snake_case. Mixing camelCase application code with
snake_case SDK calls creates visual noise rather than reducing it.

## Optional: `m_` Prefix for Private Members

Teams that want stronger "this is internal state" signaling may adopt:

```cpp
class RelayController {
private:
    bool m_is_shedding = false;
};
```

This is common in Qt, automotive embedded, and MISRA-adjacent codebases.
Not currently enforced in this project — adopt if the team agrees.

## References

- [Google C++ Style Guide](https://google.github.io/styleguide/cppguide.html)
- [ESP-IDF Coding Style](https://docs.espressif.com/projects/esp-idf/en/latest/esp32/contribute/style-guide.html)
- [MISRA C++ 2023 Guidelines](https://misra.org.uk/)

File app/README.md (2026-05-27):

# App — Nepal Grid Peak Load Controller Dashboard

Flutter-based network operator telemetry dashboard for the Smart Demand Response Gateway. Provides real-time visualization of gateway power readings, grid load status, and peak-stress load-shedding events.

## Architecture

The app follows Clean Architecture with feature-based packaging and Riverpod for state management.

```
app/lib/
├── main.dart                          # Entry point — ProviderScope + MaterialApp
├── core/
│   ├── constants.dart                 # API URLs, polling intervals, color tokens
│   └── theme.dart                     # Material theme configuration
└── features/
    └── dashboard/
        ├── data/                      # Repository implementations, WebSocket client
        ├── domain/                    # Domain models, repository interfaces
        ├── presentation/             # DashboardScreen, widgets
        └── providers/                # Riverpod providers (code-generated)
```

## Features

- Real-time power telemetry display from connected ESP32 gateways
- WebSocket-driven live updates (no polling required for status changes)
- Visual grid status indicators: normal (green), elevated (amber), peak stress (red)
- Gateway online/offline status tracking
- Responsive to peak-stress events with faster refresh intervals (3s vs 10s)

## Getting Started

### Prerequisites

- Flutter SDK 3.11.5+
- Dart SDK 3.11.5+
- Running backend server (see `../backend/README.md`)

### Run

```bash
# Fetch dependencies
make get

# Run code generation (Riverpod providers)
make build-runner

# Launch in debug mode
make run
```

### Build

```bash
# Release APK
make build-apk
```

### Test & Lint

```bash
make test
make analyze
```

## Configuration

Backend connection is configured in `lib/core/constants.dart`:

| Setting | Default | Description |
| --- | --- | --- |
| `apiBaseUrl` | `http://localhost:8080` | Backend REST API base URL |
| `dashboardWsUrl` | `ws://localhost:8080/ws/dashboard` | WebSocket endpoint for live grid updates |
| `gridStatusPollInterval` | 10s | Fallback polling interval |
| `peakStressPollInterval` | 3s | Faster polling during peak stress |

## Dependencies

| Package | Purpose |
| --- | --- |
| `hooks_riverpod` | State management with hooks integration |
| `riverpod_annotation` | Code-generated providers |
| `flutter_hooks` | Lifecycle-aware widget hooks |
| `web_socket_channel`  | WebSocket client for real-time updates  |
| `http` | HTTP client for REST API calls |

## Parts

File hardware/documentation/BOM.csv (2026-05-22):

Reference | Value | Footprint | Quantity | Manufacturer | MPN | Description | Supplier | Unit Cost (USD)
J1 | 230VAC_IN | TerminalBlock_bornier-2_P5.08mm | 1 | Phoenix Contact | 1729018 | 2-pos screw terminal 5.08mm pitch | LCSC | 0.35
F1 | 5A Fast-Blow | Fuseholder5x20_Horiz_SemiClosed | 1 | Littelfuse | 0215005.MXP | 5A 250V ceramic fuse 5x20mm | Mouser | 0.45
D1 | P6KE250CA | D_DO-201_P15.24mm_Horizontal | 1 | Littelfuse | P6KE250CA | 250V bidirectional TVS diode | Mouser | 0.85
U1 | HLK-PM01 | Converter_ACDC_HiLink_HLK-PMxx | 1 | Hi-Link | HLK-PM01 | 230VAC to 5VDC 3W AC-DC module | AliExpress | 2.50
C1 | 100uF/16V | CP_Radial_D6.3mm_P2.50mm | 1 | Nichicon | UVR1C101MDD | 100uF 16V electrolytic capacitor | LCSC | 0.12
U2 | AMS1117-3.3 | SOT-223-3_TabPin2 | 1 | AMS | AMS1117-3.3 | 3.3V 1A LDO voltage regulator | LCSC | 0.15
C2 | 10uF | C_0805_2012Metric | 1 | Samsung | CL21A106KPFNNNE | 10uF 10V X5R ceramic capacitor | LCSC | 0.05
C3 | 22uF | C_0805_2012Metric | 1 | Samsung | CL21A226MQQNNNE | 22uF 6.3V X5R ceramic capacitor | LCSC | 0.06
J2 | SCT-013-030 | Jack_3.5mm_Horizontal | 1 | YHDC | SCT-013-030 | 30A non-invasive CT sensor + jack | AliExpress | 4.50
R1 | 33R 1% | R_0805_2012Metric | 1 | Yageo | RC0805FR-0733RL | 33 ohm 1% 0.125W resistor | LCSC | 0.01
R2 | 10K 1% | R_0805_2012Metric | 1 | Yageo | RC0805FR-0710KL | 10K ohm 1% 0.125W resistor | LCSC | 0.01
R3 | 10K 1% | R_0805_2012Metric | 1 | Yageo | RC0805FR-0710KL | 10K ohm 1% 0.125W resistor | LCSC | 0.01
C4 | 10uF | C_0805_2012Metric | 1 | Samsung | CL21A106KPFNNNE | 10uF 10V X5R ceramic capacitor | LCSC | 0.05
C5 | 10uF | C_0805_2012Metric | 1 | Samsung | CL21A106KPFNNNE | 10uF 10V X5R ceramic capacitor | LCSC | 0.05
R4 | 1K | R_0805_2012Metric | 1 | Yageo | RC0805FR-071KL | 1K ohm 1% 0.125W resistor | LCSC | 0.01
D2 | BAT54 | D_SOD-323 | 1 | Nexperia | BAT54 | 30V Schottky barrier diode | LCSC | 0.03
D3 | BAT54 | D_SOD-323 | 1 | Nexperia | BAT54 | 30V Schottky barrier diode | LCSC | 0.03
R5 | 330R | R_0805_2012Metric | 1 | Yageo | RC0805FR-07330RL | 330 ohm 1% 0.125W resistor | LCSC | 0.01
U3 | PC817 | DIP-4_W7.62mm | 1 | Sharp | PC817X2NSZ0F | Optocoupler 5kV isolation CTR 50-300% | LCSC | 0.12
R6 | 1K | R_0805_2012Metric | 1 | Yageo | RC0805FR-071KL | 1K ohm 1% 0.125W resistor | LCSC | 0.01
Q1 | BC547B | TO-92_Inline | 1 | ON Semi | BC547BTA | NPN transistor 45V 100mA | LCSC | 0.03
D4 | 1N4148 | D_SOD-323 | 1 | Nexperia | 1N4148WS | 75V 150mA fast switching diode | LCSC | 0.02
K1 | SRD-05VDC-SL-C | Relay_SPDT_SANYOU_SRD | 1 | Songle | SRD-05VDC-SL-C | 5V SPDT relay 10A 250VAC | LCSC | 0.65
D5 | P6KE250CA | D_DO-201_P15.24mm_Horizontal | 1 | Littelfuse | P6KE250CA | 250V bidirectional TVS diode | Mouser | 0.85
J3 | LOAD_OUT | TerminalBlock_bornier-3_P5.08mm | 1 | Phoenix Contact | 1729021 | 3-pos screw terminal 5.08mm pitch | LCSC | 0.50
D6 | LED_Green | LED_0805_2012Metric | 1 | Everlight | 19-217/GHC-YR1S2/3T | Green LED 0805 20mA | LCSC | 0.02
R7 | 470R | R_0805_2012Metric | 1 | Yageo | RC0805FR-07470RL | 470 ohm 1% 0.125W resistor | LCSC | 0.01
U4 | ESP32-WROOM-32 | ESP32-WROOM-32 | 1 | Espressif | ESP32-WROOM-32E | WiFi+BT MCU module 4MB flash | LCSC | 3.20
C6 | 100nF | C_0402_1005Metric | 1 | Samsung | CL05B104KO5NNNC | 100nF 16V X7R ceramic capacitor | LCSC | 0.01
C7 | 10uF | C_0805_2012Metric | 1 | Samsung | CL21A106KPFNNNE | 10uF 10V X5R ceramic capacitor | LCSC | 0.05
R8 | 10K | R_0805_2012Metric | 1 | Yageo | RC0805FR-0710KL | 10K ohm 1% 0.125W resistor | LCSC | 0.01
SW1 | BOOT | SW_SPST_TL3342 | 1 | E-Switch | TL3342F160QG | Tactile switch SPST 50mA 12V | LCSC | 0.08
SW2 | RESET | SW_SPST_TL3342 | 1 | E-Switch | TL3342F160QG | Tactile switch SPST 50mA 12V | LCSC | 0.08
J4 | UART_HDR | PinHeader_1x04_P2.54mm_Vertical | 1 | Generic | PH-1x4-2.54 | 4-pin male header 2.54mm pitch | LCSC | 0.05
D7 | LED_Blue | LED_0805_2012Metric | 1 | Everlight | 19-217/BHC-ZL1M2RY/3T | Blue LED 0805 20mA | LCSC | 0.03
R9 | 1K | R_0805_2012Metric | 1 | Yageo | RC0805FR-071KL | 1K ohm 1% 0.125W resistor | LCSC | 0.01
D8 | PESD3V3L1BA | D_SOD-323 | 1 | Nexperia | PESD3V3L1BA | 3.3V ESD protection diode | LCSC | 0.04
U5 | ADS1115IDGS | TSSOP-10_3x3mm_P0.5mm | 1 | Texas Instruments | ADS1115IDGSR | 16-bit 860SPS 4-ch delta-sigma ADC I2C | LCSC | 4.50

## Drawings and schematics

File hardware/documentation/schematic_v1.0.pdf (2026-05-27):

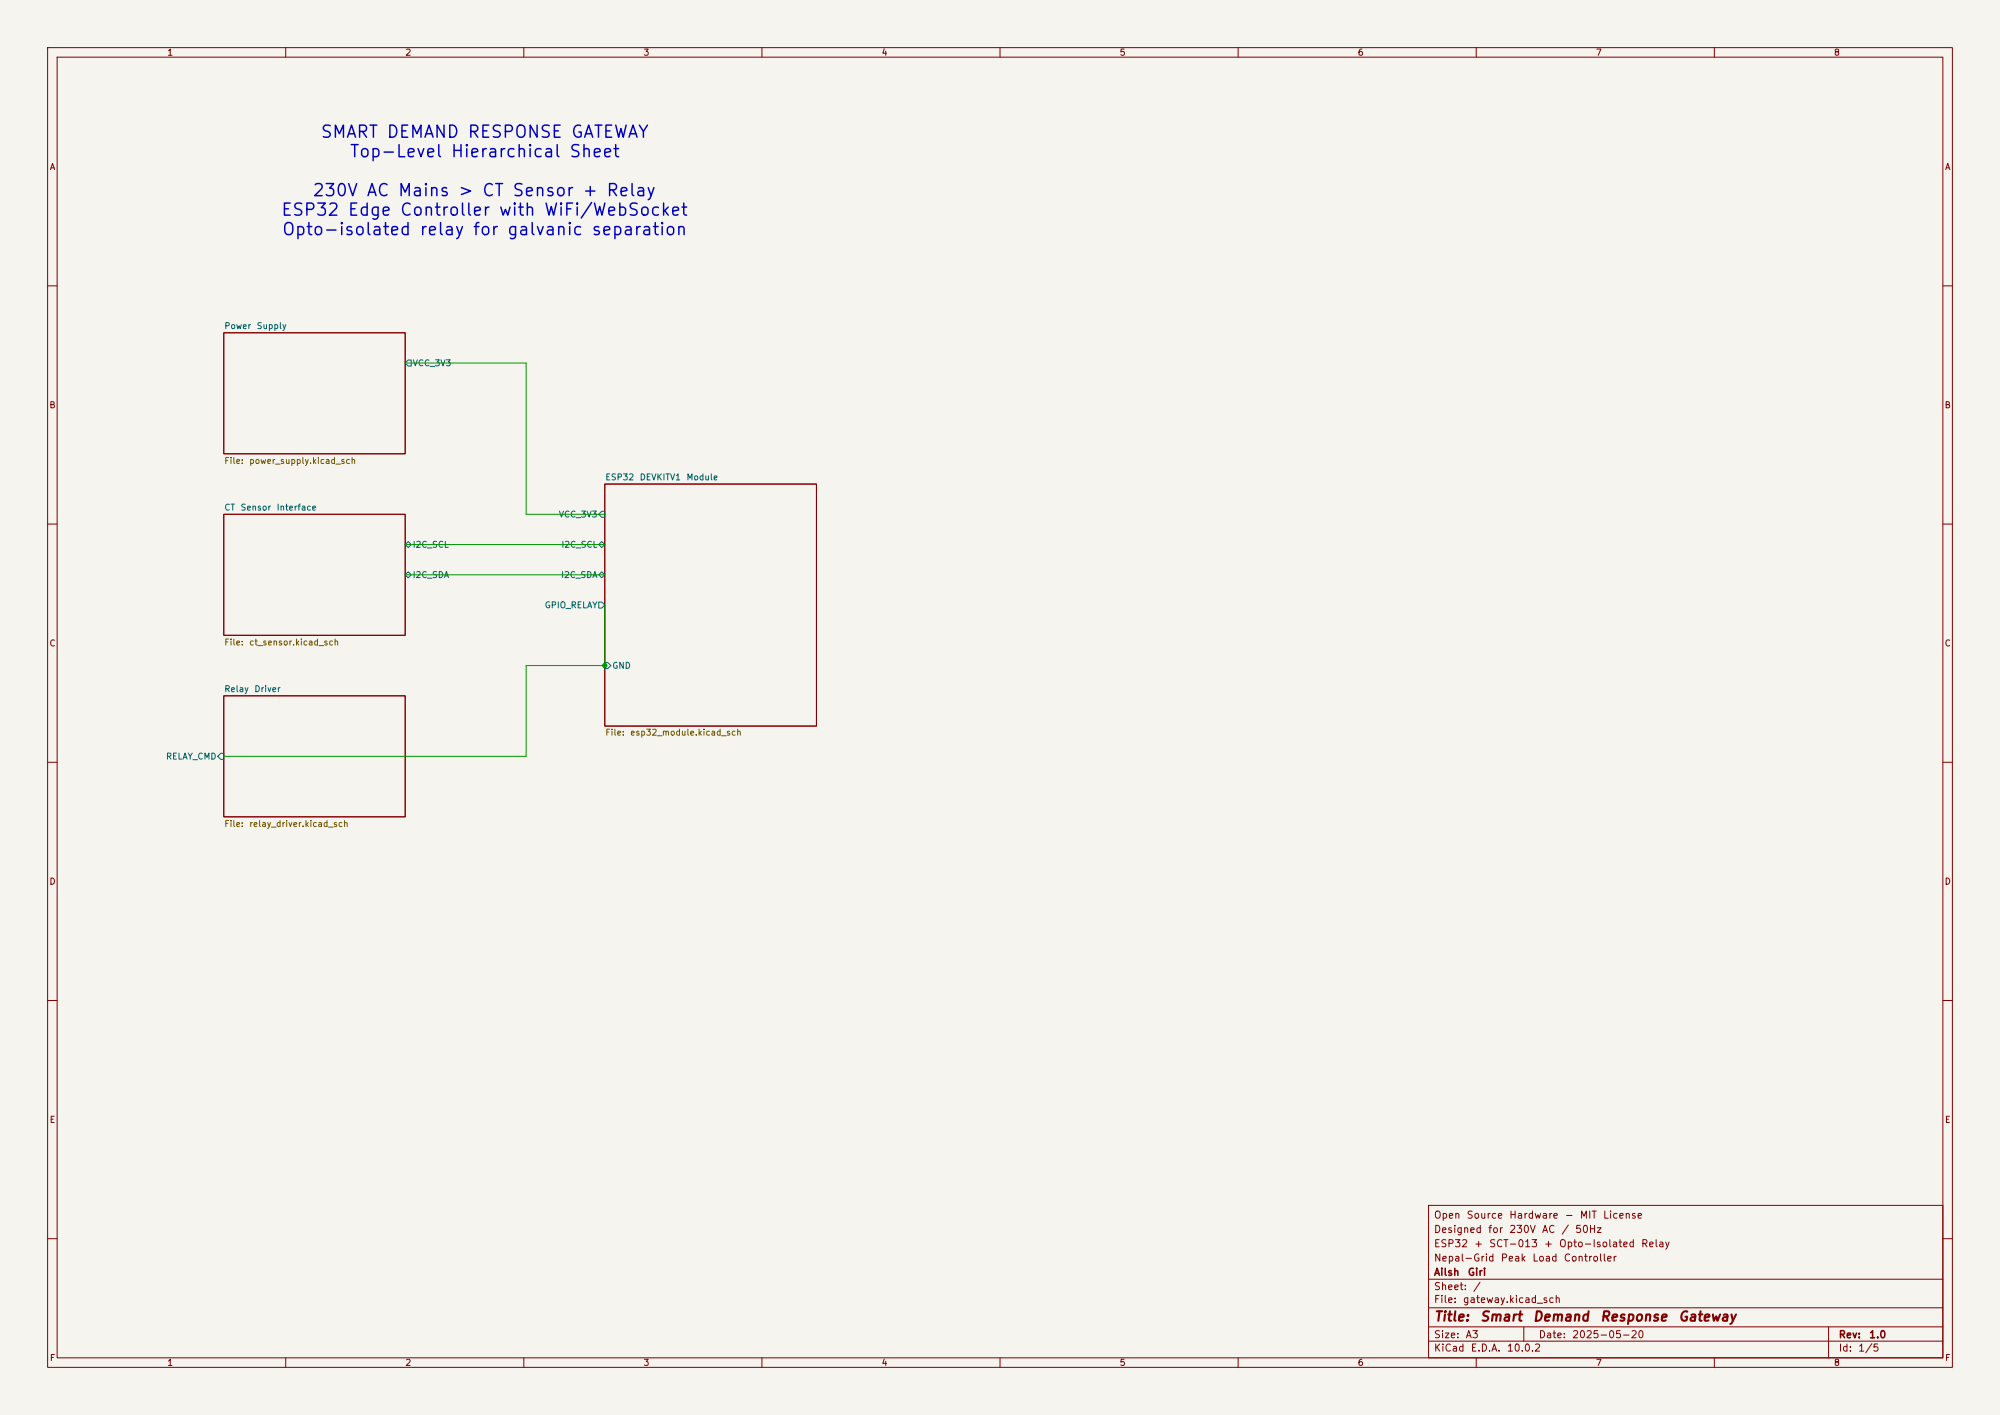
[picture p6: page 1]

SMART DEMAND RESPONSE GATEWAY
Top-Level Hierarchical Sheet

230V AC Mains > CT Sensor + Relay
ESP32 Edge Controller with WiFi/WebSocket
Opto-isolated relay for galvanic separation

Open Source Hardware - MIT License
Designed for 230V AC / 50Hz
ESP32 + SCT-013 + Opto-Isolated Relay
Nepal-Grid Peak Load Controller
Ailsh Giri
Sheet: /
File: gateway.kicad_sch
Title: Smart Demand Response Gateway

Size: A3 | Rev: 1.0
KiCad E.D.A. 10.0.2 | Id: 1/5 | F Date: 2025-05-20

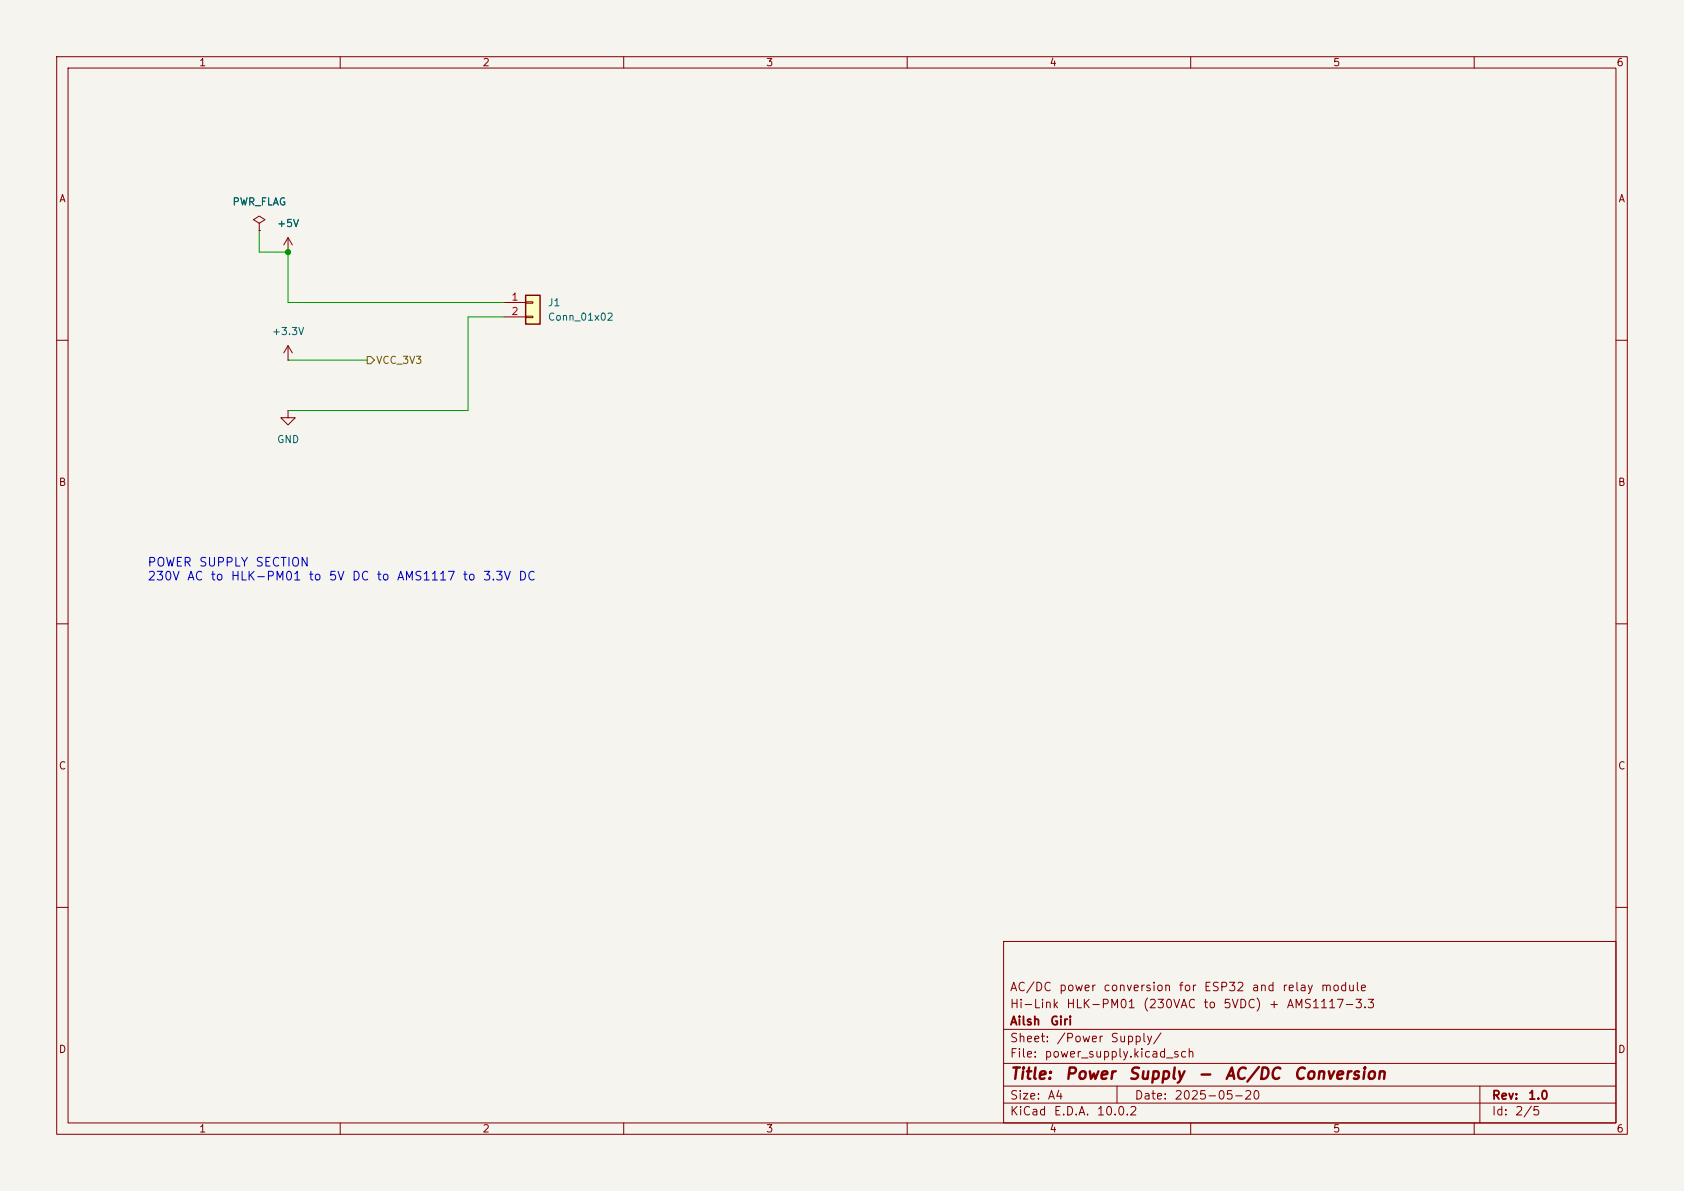
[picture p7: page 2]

230V AC to HLK-PM01 to 5V DC to AMS1117 to 3.3V DC

AC/DC power conversion for ESP32 and relay module
Hi-Link HLK-PM01 (230VAC to 5VDC) + AMS1117-3.3
Ailsh Giri
Sheet: /Power Supply/
File: power_supply.kicad_sch
Title: Power Supply - AC/DC Conversion

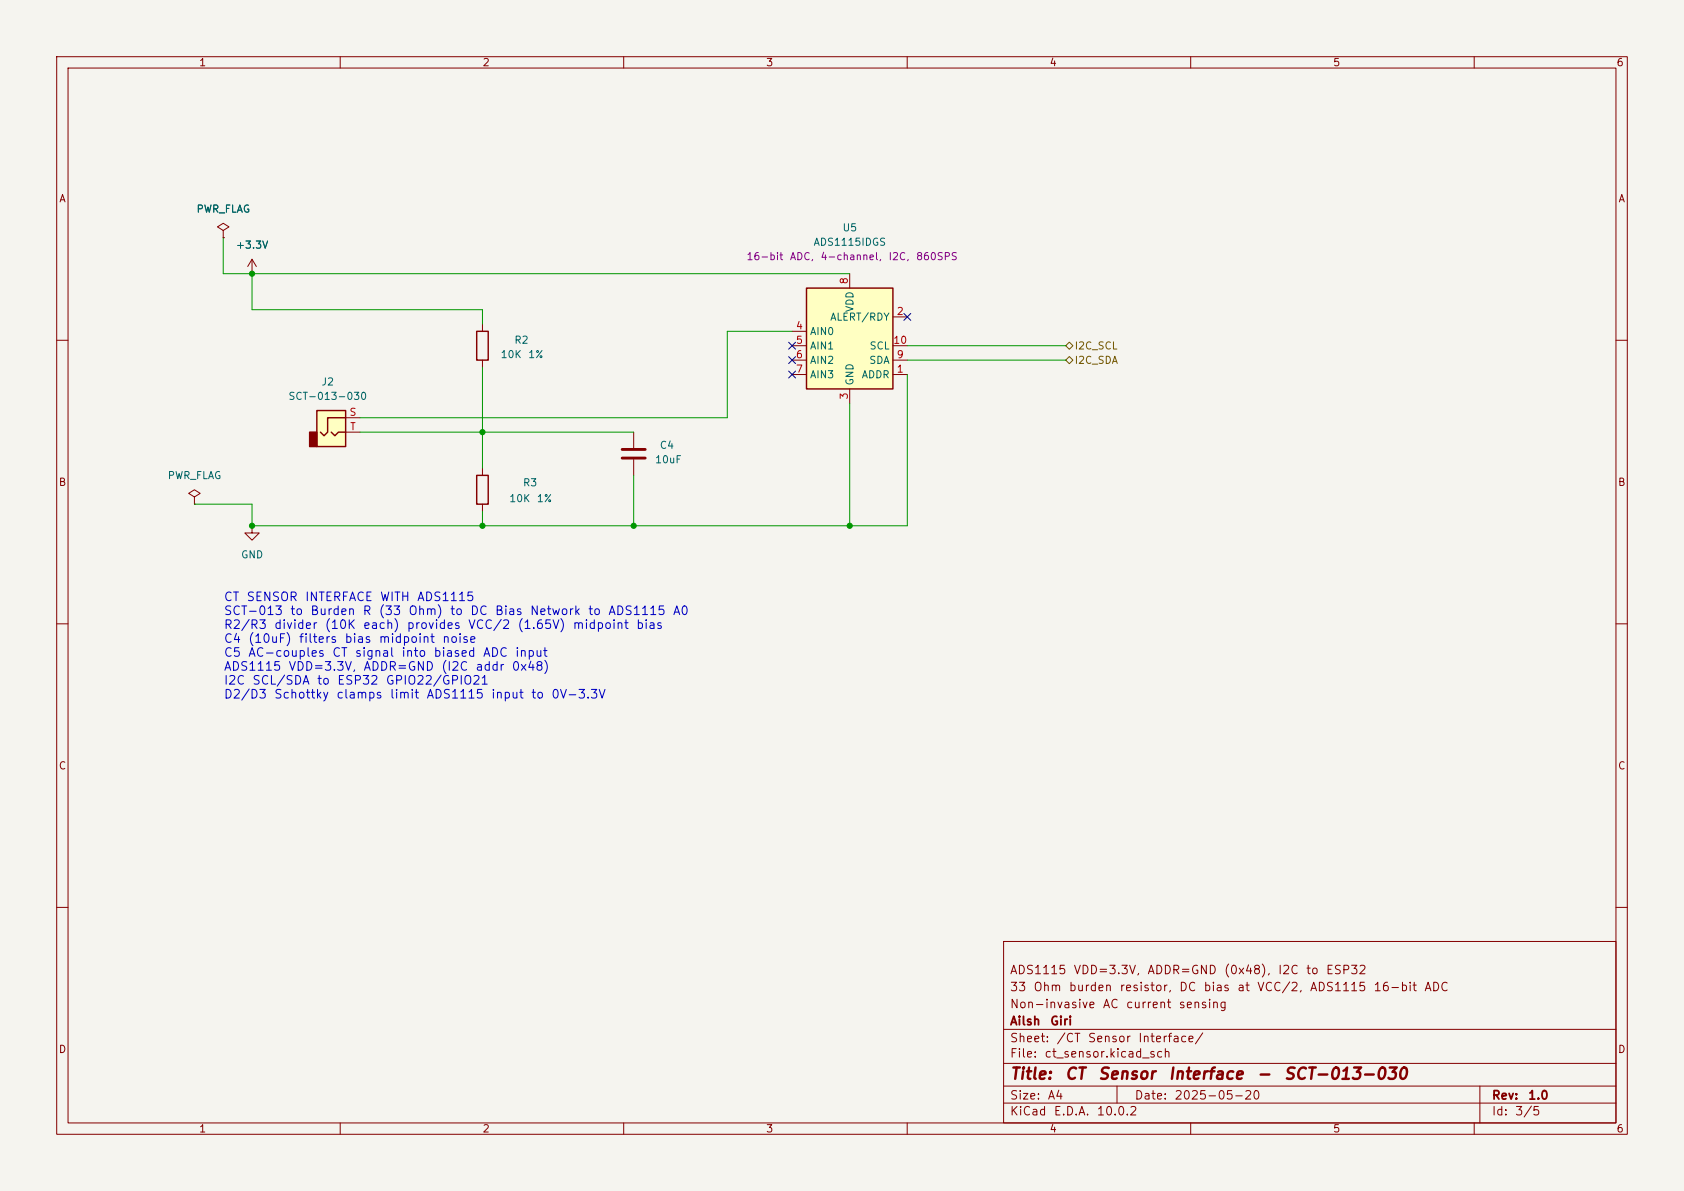
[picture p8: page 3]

D2/D3 Schottky clamps limit ADS1115 input to 0V-3.3V +3.3V PWR_FLAG

I2C_SDA CT SENSOR INTERFACE WITH ADS1115

SCT-013 to Burden R (33 Ohm) to DC Bias Network to ADS1115 A0
R2/R3 divider (10K each) provides VCC/2 (1.65V) midpoint bias
C4 (10uF) filters bias midpoint noise
C5 AC-couples CT signal into biased ADC input
ADS1115 VDD=3.3V, ADDR=GND (I2C addr 0x48)
I2C SCL/SDA to ESP32 GPIO22/GPIO21

ADS1115 VDD=3.3V, ADDR=GND (0x48), I2C to ESP32
33 Ohm burden resistor, DC bias at VCC/2, ADS1115 16-bit ADC
Non-invasive AC current sensing
Ailsh Giri
Sheet: /CT Sensor Interface/
File: ct_sensor.kicad_sch
Title: CT Sensor Interface - SCT-013-030

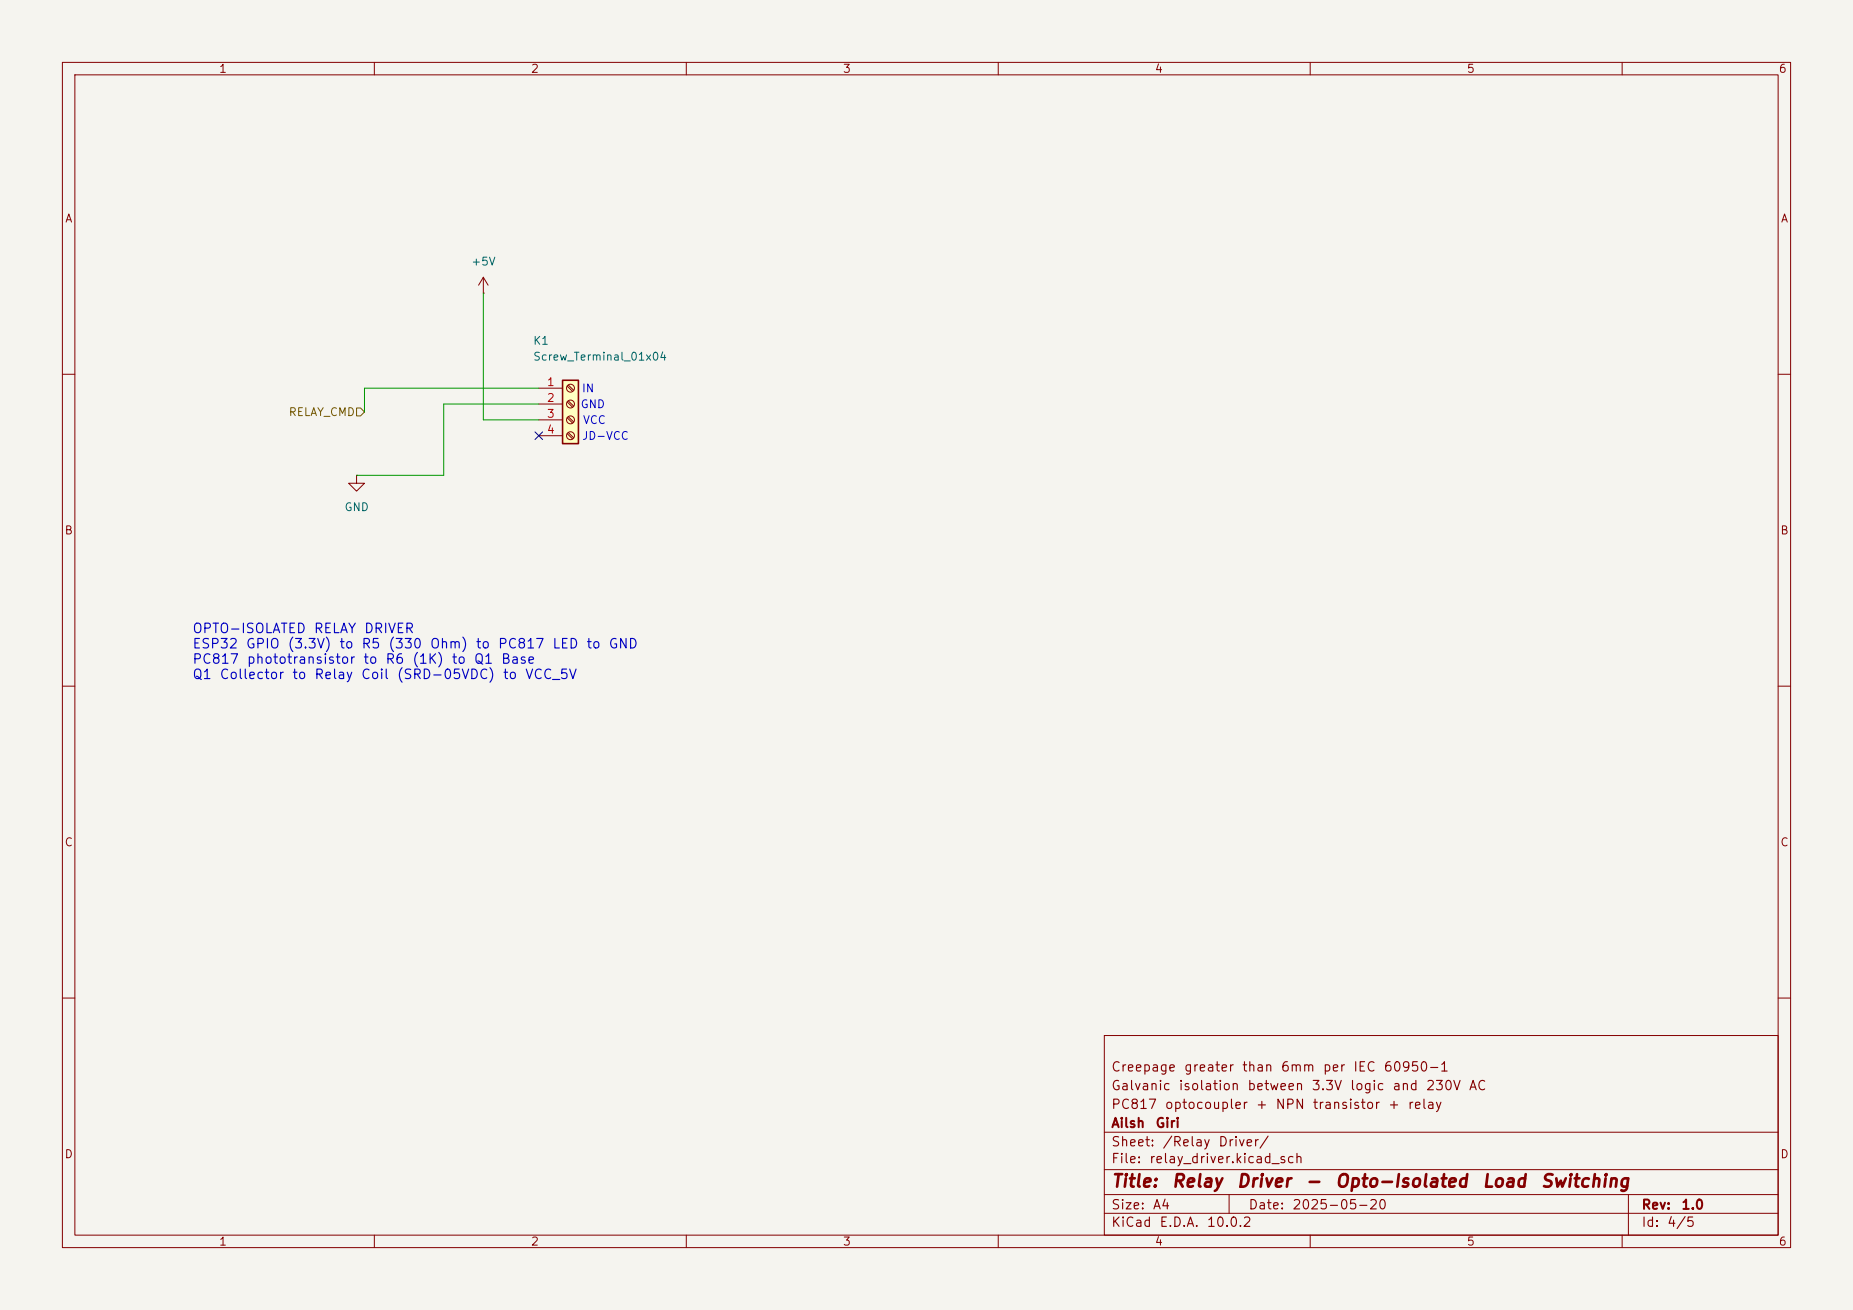
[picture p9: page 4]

JD-VCC OPTO-ISOLATED RELAY DRIVER

ESP32 GPIO (3.3V) to R5 (330 Ohm) to PC817 LED to GND
PC817 phototransistor to R6 (1K) to Q1 Base
Q1 Collector to Relay Coil (SRD-05VDC) to VCC_5V

Creepage greater than 6mm per IEC 60950-1
Galvanic isolation between 3.3V logic and 230V AC
PC817 optocoupler + NPN transistor + relay
Ailsh Giri
Sheet: /Relay Driver/
File: relay_driver.kicad_sch
Title: Relay Driver - Opto-Isolated Load Switching

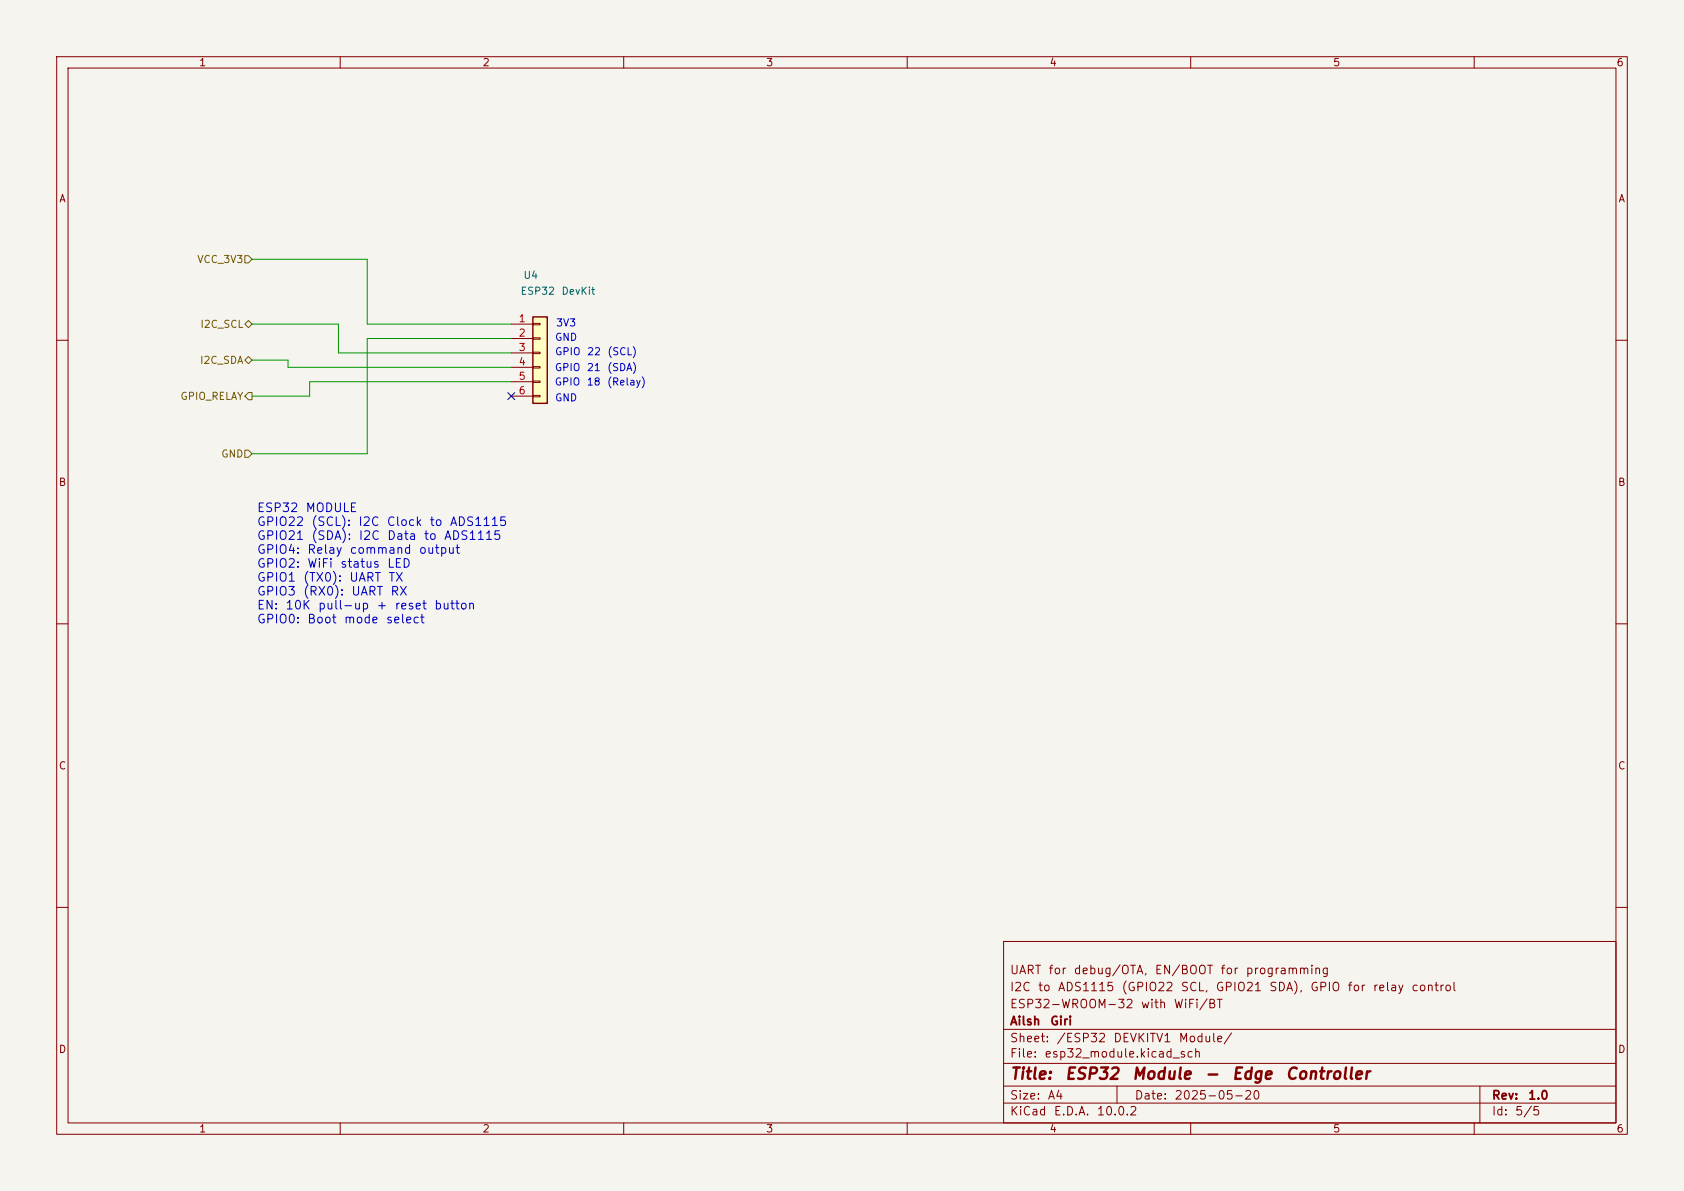
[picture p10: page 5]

GPIO 18 (Relay) 3V3 GPIO 22 (SCL)
GPIO 21 (SDA) GND

GPIO22 (SCL): I2C Clock to ADS1115
GPIO21 (SDA): I2C Data to ADS1115
GPIO4: Relay command output
GPIO2: WiFi status LED
GPIO1 (TX0): UART TX
GPIO3 (RX0): UART RX
EN: 10K pull-up + reset button

UART for debug/OTA, EN/BOOT for programming
I2C to ADS1115 (GPIO22 SCL, GPIO21 SDA), GPIO for relay control
ESP32-WROOM-32 with WiFi/BT
Ailsh Giri
Sheet: /ESP32 DEVKITV1 Module/
File: esp32_module.kicad_sch
Title: ESP32 Module - Edge Controller

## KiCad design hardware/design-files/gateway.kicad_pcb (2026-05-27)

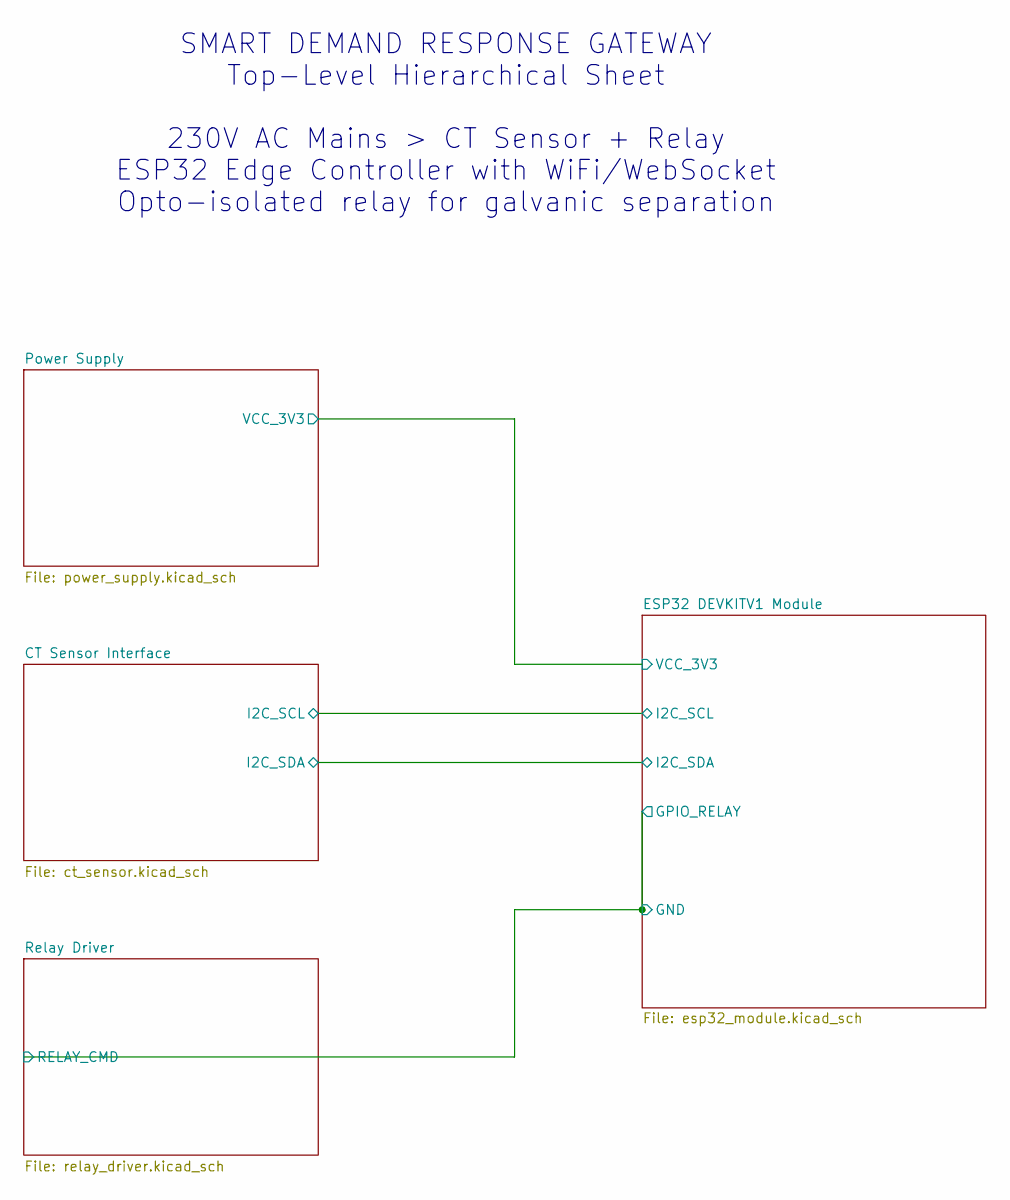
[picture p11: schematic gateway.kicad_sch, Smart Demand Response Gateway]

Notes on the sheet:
SMART DEMAND RESPONSE GATEWAY Top-Level Hierarchical Sheet 230V AC Mains > CT Sensor + Relay ESP32 Edge Controller with WiFi/WebSocket Opto-isolated relay for galvanic separation

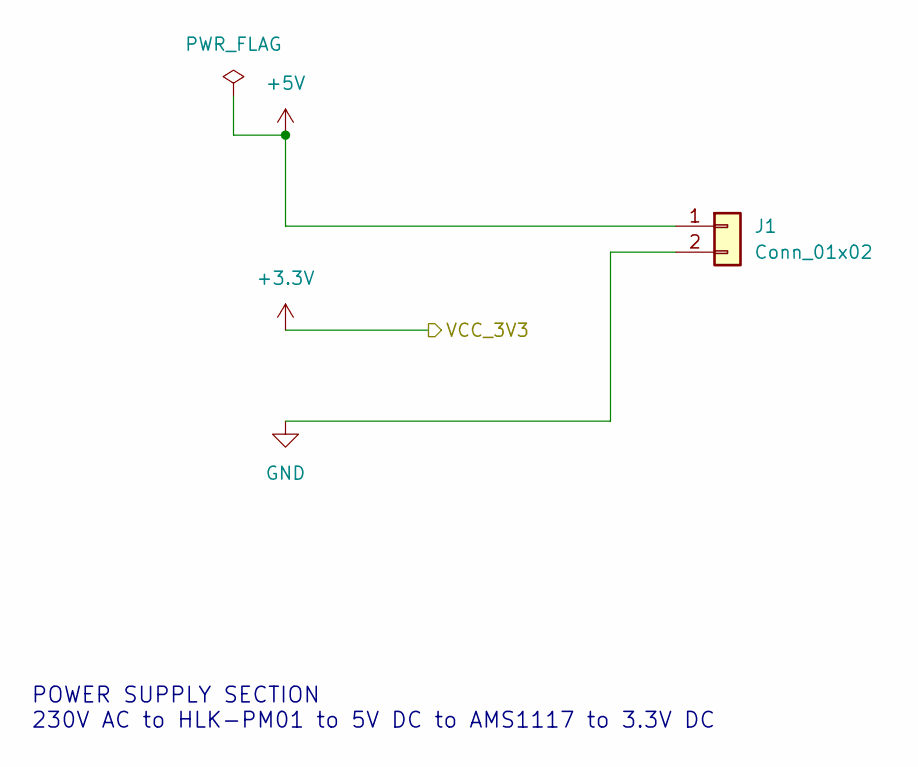
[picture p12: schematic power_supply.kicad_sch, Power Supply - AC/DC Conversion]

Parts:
J1: Conn_01x02; PinHeader_1x02_P2.54mm_Vertical

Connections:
+5V: J1.1; also elsewhere on the board
GND: J1.2; also elsewhere on the board

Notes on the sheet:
POWER SUPPLY SECTION 230V AC to HLK-PM01 to 5V DC to AMS1117 to 3.3V DC

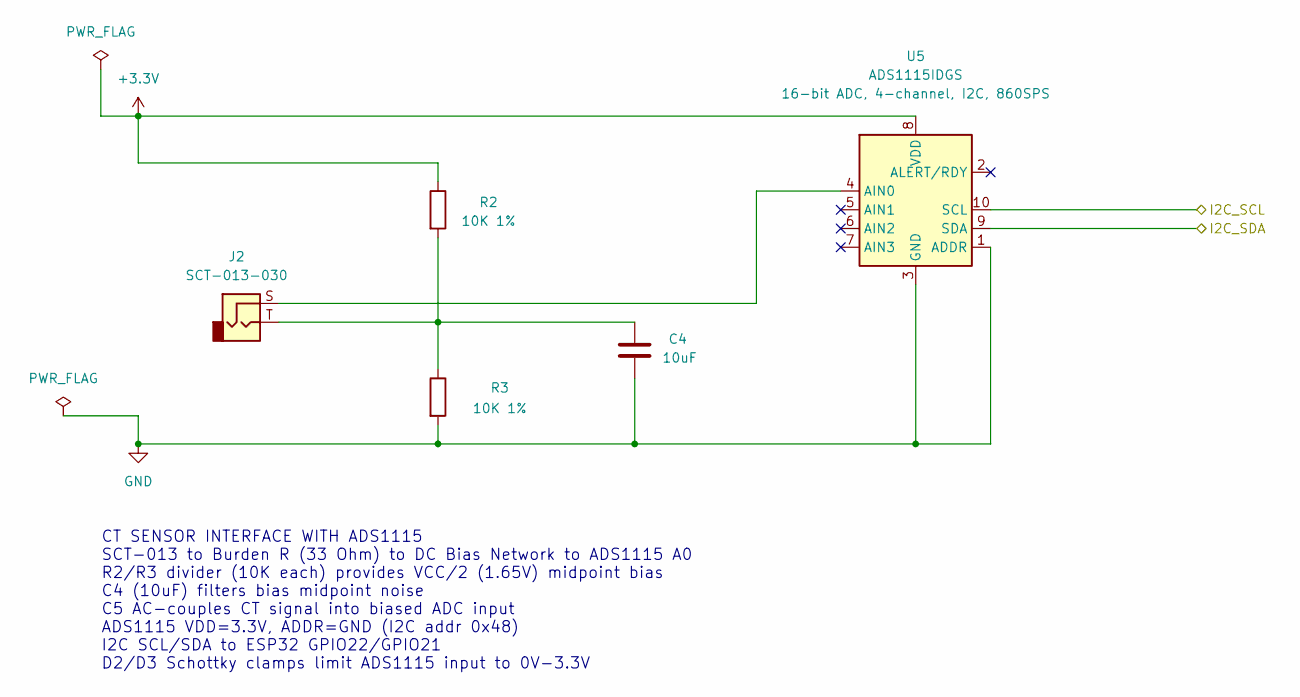
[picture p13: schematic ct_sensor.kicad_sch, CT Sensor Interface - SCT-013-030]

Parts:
C4: 10uF; C_0805_2012Metric
J2: SCT-013-030; Jack_3.5mm_Switronic_ST-005-G_horizontal
R2, R3: 10K 1%; R_0805_2012Metric
U5: ADS1115IDGS; TSSOP-10_3x3mm_P0.5mm

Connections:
+3.3V: R2.1, U5.8 (VDD); also elsewhere on the board
/CT Sensor Interface/I2C_SCL: U5.10 (SCL); also elsewhere on the board
/CT Sensor Interface/I2C_SDA: U5.9 (SDA); also elsewhere on the board
GND: C4.2, R3.2, U5.1 (ADDR), U5.3 (GND); also elsewhere on the board
unnamed: C4.1, J2.T, R2.2, R3.1
unnamed: J2.S, U5.4 (AIN0)

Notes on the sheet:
CT SENSOR INTERFACE WITH ADS1115 SCT-013 to Burden R (33 Ohm) to DC Bias Network to ADS1115 A0 R2/R3 divider (10K each) provides VCC/2 (1.65V) midpoint bias C4 (10uF) filters bias midpoint noise C5 AC-couples CT signal into biased ADC input ADS1115 VDD=3.3V, ADDR=GND (I2C addr 0x48) I2C SCL/SDA to 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

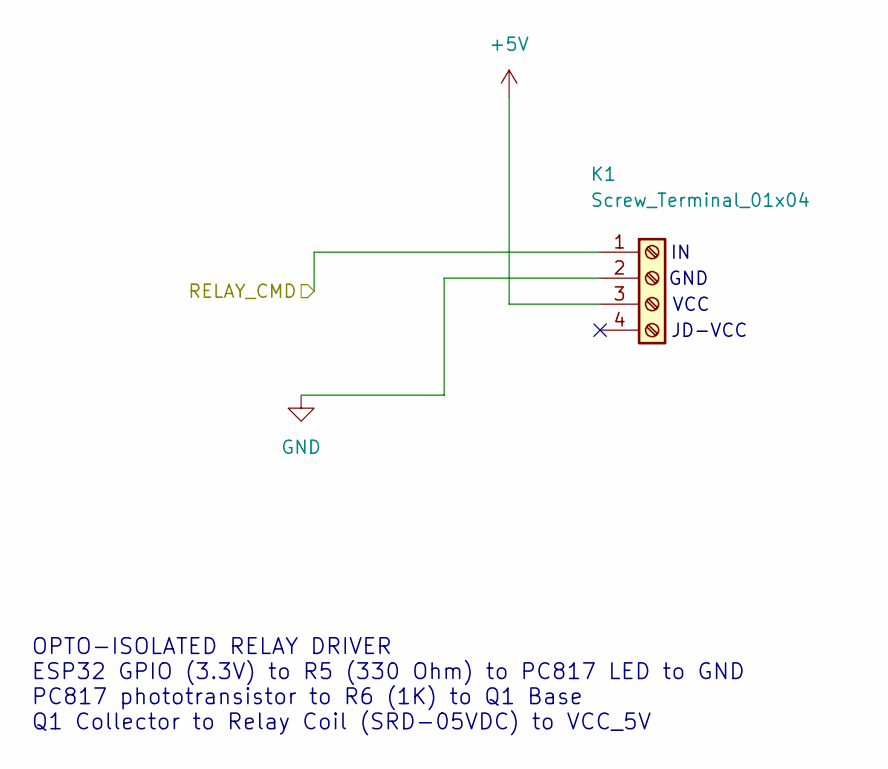
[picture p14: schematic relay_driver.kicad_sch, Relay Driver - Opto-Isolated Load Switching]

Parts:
K1: Screw_Terminal_01x04; PinHeader_1x04_P2.54mm_Vertical

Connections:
+5V: K1.3; also elsewhere on the board
/ESP32 DEVKITV1 Module/GND: K1.1; also elsewhere on the board
GND: K1.2; also elsewhere on the board

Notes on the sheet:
JD-VCC
VCC
GND
OPTO-ISOLATED RELAY DRIVER ESP32 GPIO (3.3V) to R5 (330 Ohm) to PC817 LED to GND PC817 phototransistor to R6 (1K) to Q1 Base Q1 Collector to Relay Coil (SRD-05VDC) to VCC_5V

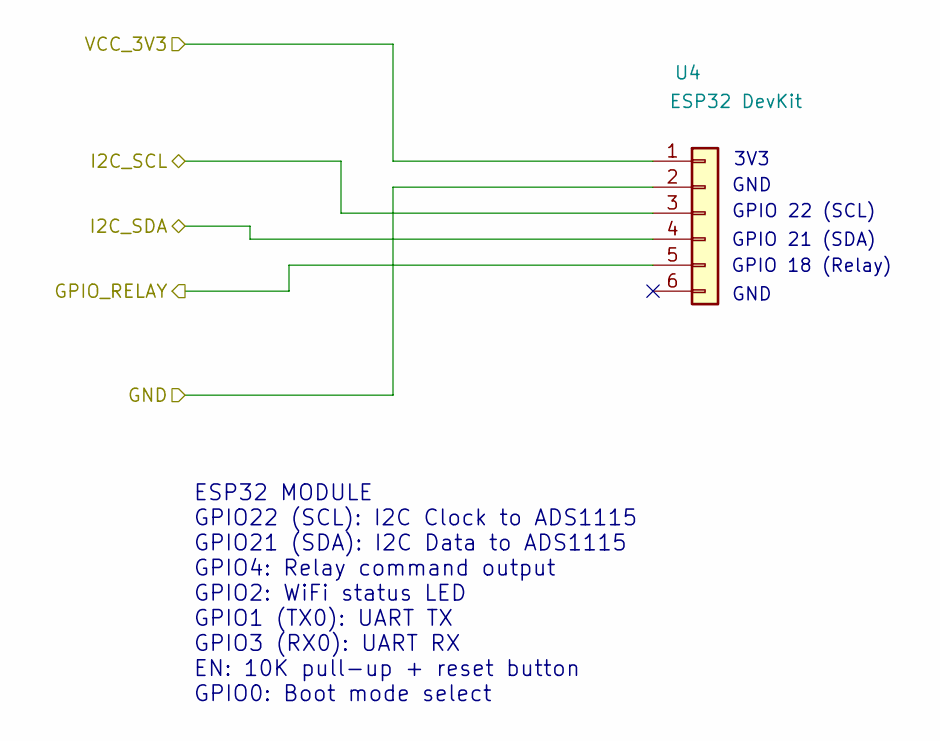
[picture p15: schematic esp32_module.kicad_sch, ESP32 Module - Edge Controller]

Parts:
U4: ESP32 DevKit; PinHeader_1x06_P2.54mm_Vertical

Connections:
+3.3V: U4.1; also elsewhere on the board
/CT Sensor Interface/I2C_SCL: U4.3; also elsewhere on the board
/CT Sensor Interface/I2C_SDA: U4.4; also elsewhere on the board
/ESP32 DEVKITV1 Module/GND: U4.2, U4.5; also elsewhere on the board

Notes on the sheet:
GPIO 22 (SCL)
GND
ESP32 MODULE GPIO22 (SCL): I2C Clock to ADS1115 GPIO21 (SDA): I2C Data to ADS1115 GPIO4: Relay command output GPIO2: WiFi status LED GPIO1 (TX0): UART TX GPIO3 (RX0): UART RX EN: 10K pull-up + reset button GPIO0: Boot mode select
3V3
GPIO 18 (Relay)
GPIO 21 (SDA)

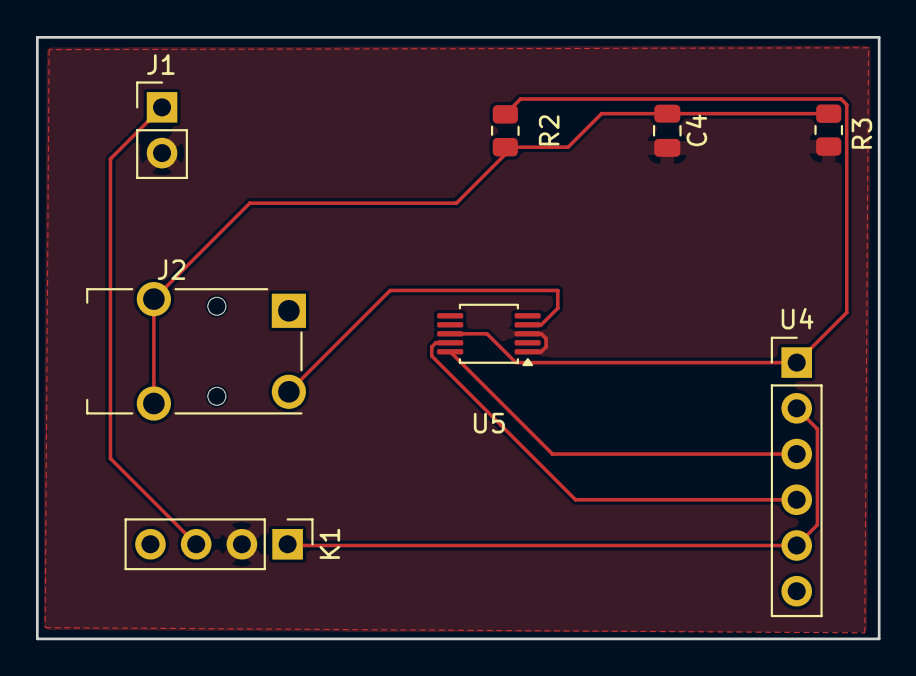
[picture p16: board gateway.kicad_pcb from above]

Board: 2 copper layers, 46.8 x 33.4 mm, 8 parts (0 on the bottom side), 8 nets.

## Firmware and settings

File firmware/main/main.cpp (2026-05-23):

/**
 * @file main.cpp
 * @brief Firmware entry point for the Nepal Grid Peak Load Controller gateway.
 *
 * Orchestrates the dual-core FreeRTOS task architecture using statically
 * allocated class instances:
 *   - Sensor Task on Core 1 (priority 2): deterministic I2C/ADS1115 sampling
 *   - Network Task on Core 0 (priority 1): backend communication
 *
 * Core separation ensures network I/O latency (WiFi interrupts, TCP retransmits)
 * cannot introduce jitter into the 500ms ADS1115 sampling loop.
 *
 * All objects are statically allocated at compile time to protect the heap.
 */

#include "freertos/FreeRTOS.h"
#include "freertos/task.h"
#include "esp_log.h"
#include "nvs_flash.h"

#include "core/config.h"
#include "core/nvs_config.hpp"
#include "core/gateway_state.hpp"
#include "features/sensor/current_sensor.hpp"
#include "features/relay/relay_controller.hpp"
#include "features/network/network_client.hpp"

static const char *TAG = "main";

// Statically allocate all instances at compile time to protect the heap
static GatewayState gateway_state;
static CurrentSensor ct_sensor(CT_CALIBRATION_FACTOR);
static RelayController relay_controller;
static NvsConfig nvs_config;
static NetworkClient network_client(gateway_state, relay_controller, nvs_config);

void Task_ReadSensors(void *pvParameters)
{
    ESP_LOGI(TAG, "Sensor task started: RMS over %d AC cycles (%dms), "
             "%d-reading smoothing window, %ums interval",
             RMS_CYCLE_COUNT, RMS_WINDOW_DURATION_MS,
             SMOOTHING_WINDOW_SIZE, SAMPLE_INTERVAL_MS);

    while (true) {
        float current_amps = ct_sensor.read_smoothed_amps();
        gateway_state.write_power(current_amps);
        vTaskDelay(pdMS_TO_TICKS(SAMPLE_INTERVAL_MS));
    }
}

void Task_NetworkSync(void *pvParameters)
{
    ESP_LOGI(TAG, "Network task started, telemetry interval=%ums", NETWORK_POLL_INTERVAL_MS);

    while (true) {
        network_client.send_telemetry();
        vTaskDelay(pdMS_TO_TICKS(NETWORK_POLL_INTERVAL_MS));
    }
}

extern "C" void app_main(void)
{
    // NVS is required by the Wi-Fi driver for RF calibration storage
    esp_err_t ret = nvs_flash_init();
    if (ret == ESP_ERR_NVS_NO_FREE_PAGES || ret == ESP_ERR_NVS_NEW_VERSION_FOUND) {
        ESP_ERROR_CHECK(nvs_flash_erase());
        ret = nvs_flash_init();
    }
    ESP_ERROR_CHECK(ret);

    // Load runtime configuration from NVS (falls back to Kconfig defaults)
    nvs_config.load();

    if (!gateway_state.init()) {
        ESP_LOGE(TAG, "Failed to initialize gateway state");
        return;
    }

    if (!ct_sensor.init()) {
        ESP_LOGE(TAG, "Failed to initialize current sensor");
        return;
    }

    if (!relay_controller.init()) {
        ESP_LOGE(TAG, "Failed to initialize relay controller");
        return;
    }

    if (!network_client.init()) {
        ESP_LOGE(TAG, "Failed to initialize network client");
        return;
    }

    // Sensor Task pinned to Core 1 (priority 2)
    // Core 1 isolation provides deterministic ADC timing free from
    // network interrupt interference on Core 0.
    xTaskCreatePinnedToCore(Task_ReadSensors, "SensorTask",
                            TASK_STACK_SIZE, nullptr, 2, nullptr, 1);

    // Network Task pinned to Core 0 (priority 1)
    // Lower priority ensures sampling is never preempted by network operations.
    xTaskCreatePinnedToCore(Task_NetworkSync, "NetworkTask",
                            TASK_STACK_SIZE, nullptr, 1, nullptr, 0);

    ESP_LOGI(TAG, "Gateway started: Sensor(Core1) + Network(Core0)");
}

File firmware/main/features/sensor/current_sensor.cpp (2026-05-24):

/**
 * @file current_sensor.cpp
 * @brief CT clamp current sensing via ADS1115 16-bit ADC over I2C.
 *
 * Uses the ESP-IDF v5.x I2C master driver to communicate with the ADS1115
 * in continuous conversion mode at 860 SPS. Each measurement cycle reads
 * ~430 samples over 500ms (25 full AC cycles at 50Hz), then computes the
 * root-mean-square value after subtracting the DC bias midpoint.
 *
 * Two-stage smoothing strategy:
 *   1. RMS over 25 AC cycles — correctly handles sinusoidal waveform and
 *      inherently rejects short startup inrush surges (1-5 cycles) by
 *      averaging their energy contribution across the full measurement window.
 *   2. Rolling average of 6 consecutive RMS readings (3s total) — further
 *      suppresses motor inrush transients lasting 1-2 seconds.
 *
 * This ensures the gateway does not misinterpret a safe startup surge as
 * an emergency grid stress overload event.
 */

#include "features/sensor/current_sensor.hpp"
#include "esp_log.h"
#include "freertos/FreeRTOS.h" // IWYU pragma: keep
#include "freertos/task.h"

#include <cmath>

static const char *TAG = "current_sensor";

CurrentSensor::CurrentSensor(float cal_factor) noexcept
    : calibration_factor(cal_factor)
{
}

CurrentSensor::~CurrentSensor()
{
    if (dev_handle) {
        i2c_master_bus_rm_device(dev_handle);
    }
    if (bus_handle) {
        i2c_del_master_bus(bus_handle);
    }
}

bool CurrentSensor::write_register(uint8_t reg, uint16_t value) noexcept
{
    // ADS1115 expects: [register_pointer, MSB, LSB]
    uint8_t buf[3] = {
        reg,
        static_cast<uint8_t>((value >> 8) & 0xFF),
        static_cast<uint8_t>(value & 0xFF)
    };

    esp_err_t ret = i2c_master_transmit(dev_handle, buf, sizeof(buf), 100);
    if (ret != ESP_OK) {
        ESP_LOGE(TAG, "I2C write reg 0x%02X failed: %s", reg, esp_err_to_name(ret));
        return false;
    }
    return true;
}

bool CurrentSensor::read_register(uint8_t reg, int16_t &value) noexcept
{
    // Set register pointer, then read 2 bytes
    uint8_t reg_addr = reg;
    uint8_t buf[2] = {0};

    esp_err_t ret = i2c_master_transmit_receive(
        dev_handle, &reg_addr, 1, buf, 2, 100);
    if (ret != ESP_OK) {
        ESP_LOGE(TAG, "I2C read reg 0x%02X failed: %s", reg, esp_err_to_name(ret));
        return false;
    }

    // ADS1115 returns MSB first (big-endian)
    value = static_cast<int16_t>((buf[0] << 8) | buf[1]);
    return true;
}

bool CurrentSensor::init() noexcept
{
    // Configure I2C master bus
    i2c_master_bus_config_t bus_cfg = {};
    bus_cfg.i2c_port = I2C_NUM_0;
    bus_cfg.sda_io_num = I2C_SDA_PIN;
    bus_cfg.scl_io_num = I2C_SCL_PIN;
    bus_cfg.clk_source = I2C_CLK_SRC_DEFAULT;
    bus_cfg.glitch_ignore_cnt = 7;
    bus_cfg.flags.enable_internal_pullup = true;

    esp_err_t ret = i2c_new_master_bus(&bus_cfg, &bus_handle);
    if (ret != ESP_OK) {
        ESP_LOGE(TAG, "Failed to create I2C master bus: %s", esp_err_to_name(ret));
        return false;
    }

    // Add ADS1115 as a device on the bus
    i2c_device_config_t dev_cfg = {};
    dev_cfg.dev_addr_length = I2C_ADDR_BIT_LEN_7;
    dev_cfg.device_address = ADS1115_ADDR;
    dev_cfg.scl_speed_hz = I2C_FREQ_HZ;

    ret = i2c_master_bus_add_device(bus_handle, &dev_cfg, &dev_handle);
    if (ret != ESP_OK) {
        ESP_LOGE(TAG, "Failed to add ADS1115 device: %s", esp_err_to_name(ret));
        i2c_del_master_bus(bus_handle);
        bus_handle = nullptr;
        return false;
    }

    // Configure ADS1115 for continuous conversion on AIN0 at 860 SPS
    if (!write_register(ADS1115_REG_CONFIG, ADS1115_CONFIG_CONTINUOUS)) {
        ESP_LOGE(TAG, "Failed to configure ADS1115");
        return false;
    }

    // Allow first conversion to complete (~1.2ms at 860 SPS)
    vTaskDelay(pdMS_TO_TICKS(5));

    // Verify communication by reading back config register
    int16_t config_readback = 0;
    if (!read_register(ADS1115_REG_CONFIG, config_readback)) {
        ESP_LOGE(TAG, "Failed to verify ADS1115 config");
        return false;
    }

    ESP_LOGI(TAG, "ADS1115 initialized: addr=0x%02X, SCL=GPIO%d, SDA=GPIO%d, "
             "860 SPS continuous, PGA=±4.096V, cal_factor=%.1f A/V, "
             "RMS window=%d cycles (%dms), smoothing=%d readings",
             ADS1115_ADDR, I2C_SCL_PIN, I2C_SDA_PIN,
             calibration_factor,
             RMS_CYCLE_COUNT, RMS_WINDOW_DURATION_MS, SMOOTHING_WINDOW_SIZE);
    return true;
}

float CurrentSensor::compute_rms_amps() noexcept
{
    // Read the ADS1115 conversion register repeatedly over the RMS window.
    // At 860 SPS in continuous mode, each read returns the latest completed
    // conversion. We pace reads at ~RMS_SAMPLE_INTERVAL_US to avoid reading
    // the same conversion twice while maximizing sample count.
    //
    // The RMS calculation squares each sample, accumulates the sum, then takes
    // the square root of the mean. This correctly handles the sinusoidal AC
    // waveform — a short inrush spike lasting 1-5 cycles contributes only a
    // fraction of its energy to the 25-cycle RMS window, preventing false
    // overload detection.

    float sum_of_squares = 0.0f;
    uint16_t valid_samples = 0;

    for (uint16_t i = 0; i < RMS_TOTAL_SAMPLES; i++) {
        int16_t raw_value = 0;
        bool ok = read_register(ADS1115_REG_CONVERSION, raw_value);

        if (ok) {
            // Convert raw ADC count to voltage
            float voltage = static_cast<float>(raw_value) * ADS1115_LSB_VOLTAGE;

            // Subtract DC bias midpoint to get the AC component
            float ac_voltage = voltage - DC_BIAS_MIDPOINT_V;

            // Convert AC voltage to amperes via calibration factor
            // (CT ratio: 30A produces 1V across 33Ω burden)
            float amps = ac_voltage * calibration_factor;

            sum_of_squares += amps * amps;
            valid_samples++;
        }
        // Failed reads are silently skipped — we only need a majority of
        // samples for an accurate RMS estimate.

        // Busy-wait for the inter-sample interval (~1163µs at 860 SPS).
        // esp_rom_delay_us provides microsecond-precision delay without
        // yielding to the scheduler, maintaining deterministic sample timing.
        if (i < RMS_TOTAL_SAMPLES - 1) {
            esp_rom_delay_us(RMS_SAMPLE_INTERVAL_US);
        }
    }

    // Require at least 75% of samples to be valid for a trustworthy RMS reading
    uint16_t min_valid = (RMS_TOTAL_SAMPLES * 3) / 4;
    if (valid_samples < min_valid) {
        ESP_LOGW(TAG, "RMS burst: only %u/%u valid samples (need %u), discarding",
                 valid_samples, RMS_TOTAL_SAMPLES, min_valid);
        return -1.0f;
    }

    float mean_square = sum_of_squares / static_cast<float>(valid_samples);
    float rms_amps = sqrtf(mean_square);

    return rms_amps;
}
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

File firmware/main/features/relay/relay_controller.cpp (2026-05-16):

/**
 * @file relay_controller.cpp
 * @brief Opto-isolated relay array control implementation.
 *
 * Relay GPIO assignments target ESP32 output-capable pins that do not
 * conflict with the ADC input (GPIO34) or boot-strapping pins.
 *
 * Fail-safe design: LOW = relay de-energized = load connected. Power loss
 * reconnects all loads, preventing indefinite shedding on MCU crash.
 */

#include "features/relay/relay_controller.hpp"
#include "esp_log.h"
#include "freertos/FreeRTOS.h"
#include "freertos/task.h"

static const char *TAG = "relay_ctrl";

bool RelayController::init() noexcept
{
    gpio_config_t io_conf = {};
    io_conf.pin_bit_mask = (1ULL << RELAY_PIN_1) |
                           (1ULL << RELAY_PIN_2) |
                           (1ULL << RELAY_PIN_3);
    io_conf.mode = GPIO_MODE_OUTPUT;
    io_conf.pull_up_en = GPIO_PULLUP_DISABLE;
    io_conf.pull_down_en = GPIO_PULLDOWN_DISABLE;
    io_conf.intr_type = GPIO_INTR_DISABLE;

    esp_err_t err = gpio_config(&io_conf);
    if (err != ESP_OK) {
        ESP_LOGE(TAG, "Failed to configure relay GPIOs: %s", esp_err_to_name(err));
        return false;
    }

    // Ensure all relays start de-energized (loads connected)
    for (int i = 0; i < RELAY_COUNT; i++) {
        gpio_set_level(pins[i], 0);
    }

    is_shedding = false;
    ESP_LOGI(TAG, "Relay control initialized: %d channels, all loads connected", RELAY_COUNT);
    return true;
}

void RelayController::shed_loads() noexcept
{
    if (is_shedding) {
        return;
    }

    ESP_LOGW(TAG, "Peak stress: shedding %d load(s) in priority order", RELAY_COUNT);

    for (int i = 0; i < RELAY_COUNT; i++) {
        gpio_set_level(pins[i], 1);
        ESP_LOGI(TAG, "Relay %d ENERGIZED (load shed)", i + 1);
    }

    is_shedding = true;
}

void RelayController::restore_loads() noexcept
{
    if (!is_shedding) {
        return;
    }

    ESP_LOGI(TAG, "Peak stress cleared: restoring %d load(s) with stagger", RELAY_COUNT);

    // Restore in reverse priority order with staggered delay to prevent
    // simultaneous inrush current from motor-driven appliances
    for (int i = RELAY_COUNT - 1; i >= 0; i--) {
        gpio_set_level(pins[i], 0);
        ESP_LOGI(TAG, "Relay %d DE-ENERGIZED (load restored)", i + 1);

        if (i > 0) {
            vTaskDelay(pdMS_TO_TICKS(RESTORE_STAGGER_MS));
        }
    }

    is_shedding = false;
}

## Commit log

2026-05-16 refactor: use websockets instead of polling and add relay control logic in the firmware
2026-05-17 chore(firmware): add esp_driver_gpio dependency and refine ADC configuration
    - Add esp_driver_gpio component to CMakeLists.txt dependencies
    - Update ADC attenuation level from ADC_ATTEN_DB_11 to ADC_ATTEN_DB_12 for improved full-scale voltage range
    - Add ADC clock source configuration (ADC_RTC_CLK_SRC_DEFAULT) to unit initialization
    - Add VSCode spell check configuration for project-specific terms (espressif, WROOM, Xtensa, etc.)
    - Clarify gpio.h header source with inline comment referencing esp_driver_gpio component
2026-05-18 feat(middleware): add Unwrap method to responseWriter for WebSocket support
    - Add Unwrap() method to responseWriter that returns the underlying http.ResponseWriter
    - Enable WebSocket libraries (e.g. nhooyr.io/websocket) to access http.Hijacker for connection upgrades
    - Include documentation explaining the purpose and use case for the method
2026-05-18 feat(dashboard): add WebSocket service for real-time grid status updates
    - Add DashboardWebSocketService for persistent WebSocket connection to backend
    - Implement automatic reconnection with configurable delay on disconnection
    - Add dashboardWsUrl and wsReconnectDelay constants for WebSocket configuration
    - Replace HTTP polling with real-time stream-based updates in DashboardScreen
    - Add WebSocketConnectionState enum to track connection lifecycle
    - Update dashboard providers to integrate WebSocket service
    - Add web_socket_channel dependency to pubspec.yaml
    - Update macOS entitlements to support WebSocket connections
    - Eliminates polling overhead and provides instant grid status updates when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
2026-05-18 refactor: configure and use theme from MaterialApp instead of directly using constant values.
2026-05-19 feat(sensor): implement true RMS measurement over multiple AC cycles
    - Replace 100ms interval sampling with 500ms RMS burst measurement cycles
    - Add true RMS computation over 25 full AC cycles (500ms at 50Hz Nepal grid)
    - Implement high-frequency burst sampling at ~2kHz (40 samples/cycle) for accurate sinusoidal waveform capture
    - Reduce rolling average window from 30 to 6 readings to match new 500ms interval
    - Add two-stage smoothing: RMS over 25 cycles + rolling average of 6 readings (3s total)
    - Implement startup inrush surge rejection by averaging energy contribution across full measurement window
    - Update ADC configuration comments (DB_11 → DB_12 attenuation)
    - Add esp_timer, FreeRTOS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
    [current_sensor.cpp, main.cpp]
2026-05-21 feat(sensor): migrate from internal ADC to external ADS1115 I2C ADC
    - Replace ESP32 internal 12-bit ADC with ADS1115 16-bit delta-sigma ADC for improved resolution and linearity
    - Update CMakeLists.txt to depend on esp_driver_i2c instead of esp_adc
    - Configure I2C interface on GPIO22 (SCL) and GPIO21 (SDA) at 400kHz Fast Mode
    - Add ADS1115 register definitions and continuous conversion mode configuration (860 SPS)
    - Implement proper voltage scaling with 125µV LSB and DC bias midpoint compensation (1.65V)
    - Recalibrate CT sensor factor to 30.0 (30A per 1V across 33Ω burden) for ADS1115 voltage range
    - Update sampling calculations to reflect ADS1115's 860 SPS rate (~430 samples over 500ms wi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
    [current_sensor.cpp, main.cpp]
2026-05-21 feat(hardware): add KiCad PCB design files and documentation
    - Add complete KiCad 10.x project with hierarchical schematics for gateway PCB
    - Include design files: root schematic, CT sensor interface, ESP32 module, power supply, and relay driver circuits
    - Add PCB layout (2-layer, 100mm × 70mm) with AC/DC domain isolation per IEC 60950-1
    - Create comprehensive hardware README with directory structure, schematic hierarchy, PCB specifications, and BOM
    - Add .gitignore for KiCad lock files, backups, and generated artifacts
    - Update VS Code spell check dictionary to include "LOGI"
    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
    [ct_sensor.kicad_sch, esp32_module.kicad_sch, gateway.kicad_pcb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]
2026-05-22 feat(hardware): update KiCad schematics with component symbols and layout refinements
    - Add ADS1115 16-bit I2C ADC symbol to CT sensor schematic
    - Add AudioJack2 connector symbol for analog signal input
    - Update ESP32 module schematic with refined pin configurations
    - Update power supply schematic with improved component placement
    - Update relay driver schematic with optimized routing
    - Refine PCB layout in gateway.kicad_pcb with better trace routing
    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
    [ct_sensor.kicad_sch, esp32_module.kicad_sch, gateway.kicad_pcb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]
2026-05-22 feat(hardware): add Makefile automation and fabrication documentation
    - Add hardware/Makefile with KiCad CLI targets for exporting Gerbers, drill files, schematics, and 3D renders
    - Integrate hardware targets into root Makefile with hw- prefix for unified build system
    - Add hardware/documentation/BOM.csv with complete bill of materials including part numbers and suppliers
    - Add hardware/documentation/pcb_top_render.png high-resolution 3D board render
    - Add hardware/documentation/schematic_v1.0.pdf combined schematic export
    - Add hardware/fabrication/gateway_gerbers_v1.0.zip packaged Gerber and drill files for PCB manufacturing
    - Update hardware/.gitignore to exclude loose Gerber outputs whil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
    [BOM.csv]
2026-05-23 feat(firmware): add NVS configuration management and firmware documentation
    - Add NVS (Non-Volatile Storage) configuration layer for runtime credential management
    - Implement two-tier config system: Kconfig compile-time defaults + NVS runtime overrides
    - Create nvs_config.hpp/cpp with support for WiFi SSID/password and gateway parameters
    - Add Kconfig.projbuild for build-time configuration options and defaults
    - Update network client to use NVS config with fallback to Kconfig values
    - Add comprehensive FIRMWARE_LOGIC.md documentation covering architecture, calculations, and design patterns
    - Update CMakeLists.txt to include new NVS config component
    - Fix .gitignore to exclude /core directory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
    [main.cpp]
2026-05-24 docs: update schematic hierarchy and include Flutter in the system architecture.
2026-05-24 feat(hardware): update PCB layout and component footprints
    - Reposition ADS1115 ADC module on PCB (moved from 84.35,28 to 60.5,49.35 with 180° rotation)
    - Update CT sensor connector footprint from PinHeader to 3.5mm audio jack (Switronic ST-005-G)
    - Correct ESP32 module connector footprint from 1x02 to 1x06 pin header
    - Regenerate component UUIDs and silk screen coordinates to reflect new placements
    - Optimize PCB layout for improved signal routing and component accessibility
    [ct_sensor.kicad_sch, esp32_module.kicad_sch, gateway.kicad_pcb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]
2026-05-24 docs(hardware): update PCB documentation and fabrication files
    - Update PCB top render visualization with latest layout
    - Refresh schematic v1.0 PDF with component refinements
    - Regenerate Gerber files for gateway PCB v1.0 fabrication
    - Ensure documentation reflects current hardware design state
2026-05-27 feat(app,hardware): update dashboard precision and refine PCB layout
    - Increase grid load watts display precision from 1 to 2 decimal places in dashboard
    - Add PCB stackup configuration with FR4 dielectric specifications and copper layer thickness
    - Reposition TSSOP-10 ADS1115 ADC footprint for improved layout optimization
    - Relocate 0805 capacitor and resistor components for better signal integrity
    - Reposition 3.5mm audio jack connector (SCT-013-030 current sensor)
    - Reposition pin header connector for optimized board routing
    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
    [gateway.kicad_pcb]
